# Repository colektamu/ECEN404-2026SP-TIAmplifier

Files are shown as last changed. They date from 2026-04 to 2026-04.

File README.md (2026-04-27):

The 2025-2026 TI Amplifier Capstone Project was a senior year capstone project under Texas A&M University and sponsored by Texas Instruments. The project was completed by Haotian Guan, Cole Keating, Braeden Murdock, and Jonathan Roman under the mentorship and supervision of Alex Anderson as a contact with Texas Instruments. The files included in this GitHub repository reflect the progress updates and final version of the project.

Each folder within the repository reflects a single subsystem that contributed to the final project. 
Braeden Murdock integrated pcb power subsystem contains files relevant to the power subsystem that powered the device. 
Cole - Pre and power amp contains the files relevant to the analog subsystem, both the preamp that modulated the signal and the power amp that amplified it into the speaker output. 
Microcontroller - Jonathan Roman contains the pcb and code files for the microcontroller subsystem, used to translate mobile app inputs into potentiometer states on the audio circuits.

All other files found in the repository without a set folder are related documentation such as the Functional System Requirements and Validation Plan.

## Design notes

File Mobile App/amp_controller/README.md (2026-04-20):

# amp_controller

A new Flutter project.

## Getting Started

This project is a starting point for a Flutter application.

A few resources to get you started if this is your first Flutter project:

- [Lab: Write your first Flutter app](https://docs.flutter.dev/get-started/codelab)
- [Cookbook: Useful Flutter samples](https://docs.flutter.dev/cookbook)

For help getting started with Flutter development, view the
[online documentation](https://docs.flutter.dev/), which offers tutorials,
samples, guidance on mobile development, and a full API reference.

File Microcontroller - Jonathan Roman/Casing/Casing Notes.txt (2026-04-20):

Included in the folder is just the STL output files produced. For the actual design process, the software used was Fusion under a student license, with the repository itself available through the following link:
https://a360.co/4tlYHgb

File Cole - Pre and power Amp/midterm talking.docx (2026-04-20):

- Discuss block diagram
  - State how input signal is about 1.4V amplitude
  - Produced from 3.5mm audio jack
- Preamp stage
  - Using Baxandall 3-band config
  - Will allow for attenuation of low, mid, high frequencies
  - Volume control
  - Gain of about 1
  - Using NE5532, industry standard audio dual op amp with low noise
  - Not rail to rail, but with 12V supply it will have enough headroom
  - Design will be refined through breadboard
  - Will eventually require bespoke pcb
- Amplifier Stage
  - Will use off the shelf amplifier chip
  - Will use powerful one and underdrive it for more headroom to reduce distortion
  - Class AB is a design using push/pull transistor config, commonly used for audio designs due to low distortion
  - Must have enough headroom in output to prevent THD of 10% at 5W
- Power constraints: Due to DC only design, we don’t have the ability to provide dual voltage rails.
  - With a 12V supply, will bias around 6V and use DC decoupling capacitors for output

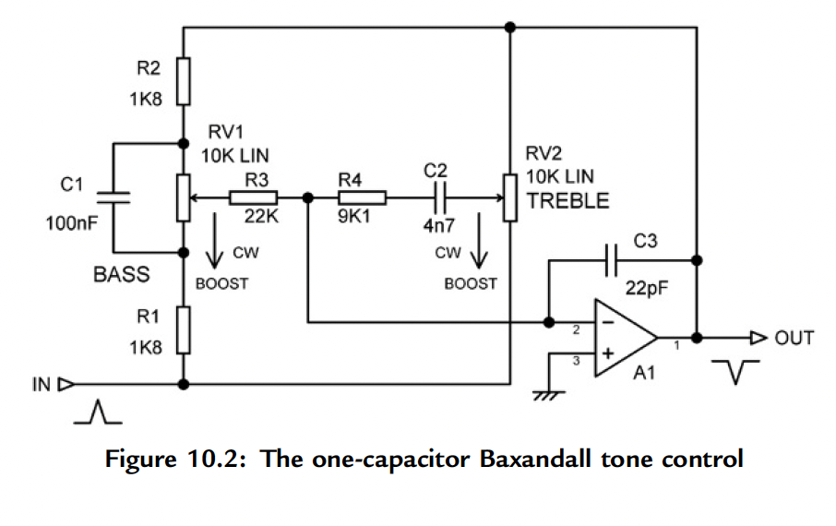
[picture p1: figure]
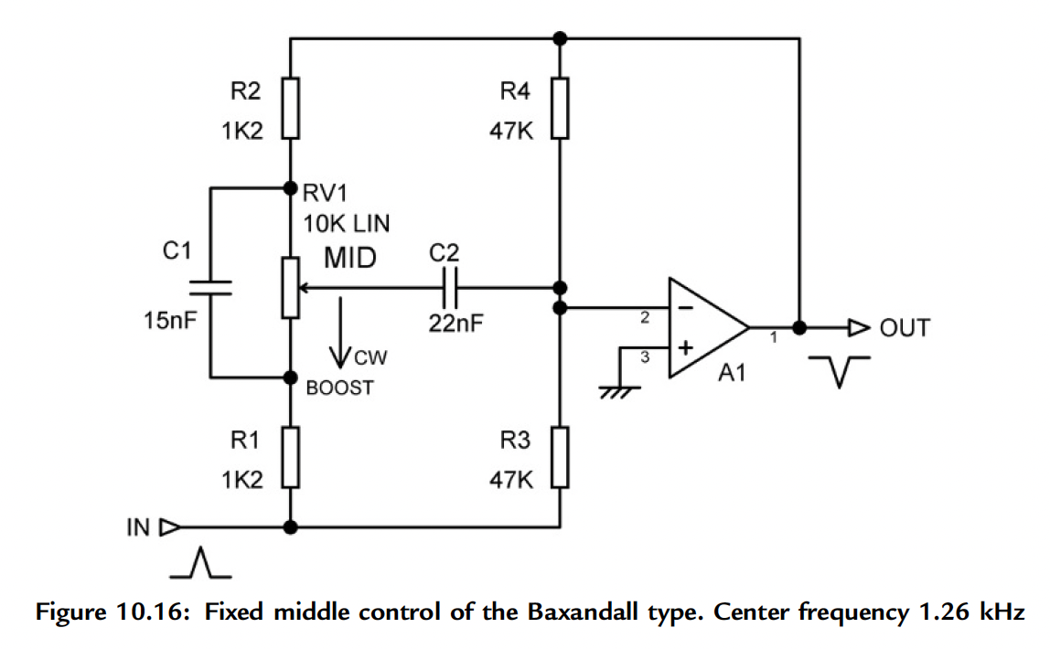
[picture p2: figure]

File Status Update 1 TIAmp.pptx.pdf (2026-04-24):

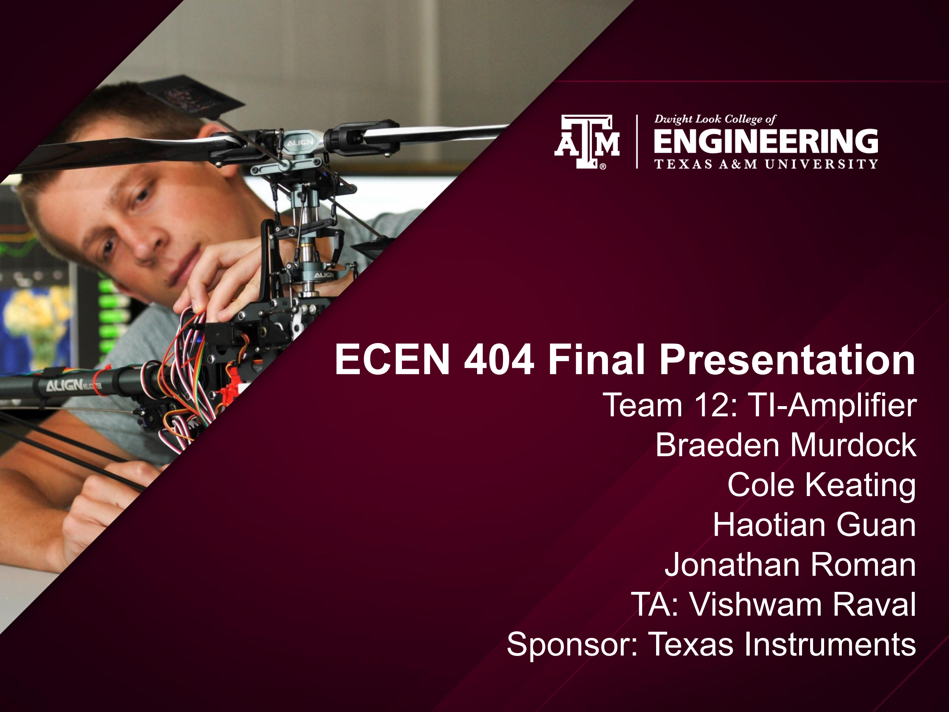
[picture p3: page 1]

# ECEN 404 Final Presentation

## Team 12: TI-Amplifier Braeden Murdock Cole Keating Haotian Guan Jonathan Roman TA: Vishwam Raval Sponsor: Texas Instruments

## Project Summary

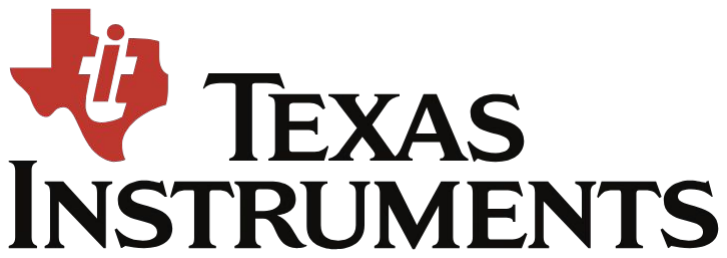
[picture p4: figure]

## Problem statement:

•Needs a system that can wirelessly amplify the sound of a 8Ω speaker from a mobile app.

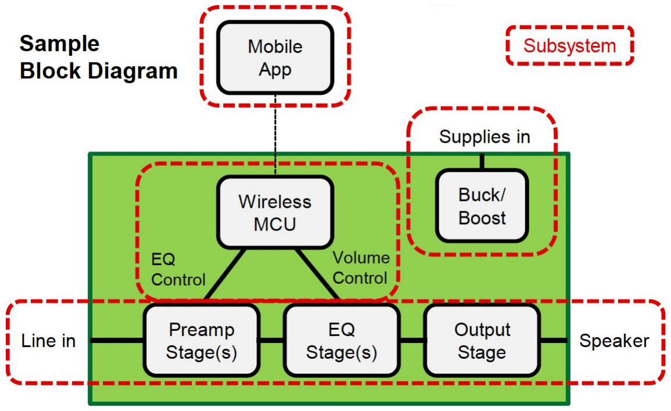
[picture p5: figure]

## Our Solution:

•The system being developed will use a MCU to communicate with a mobile app in order to control a system of amplifiers to adjust volume and EQ of the speaker using a aux input.

2

# System Overview

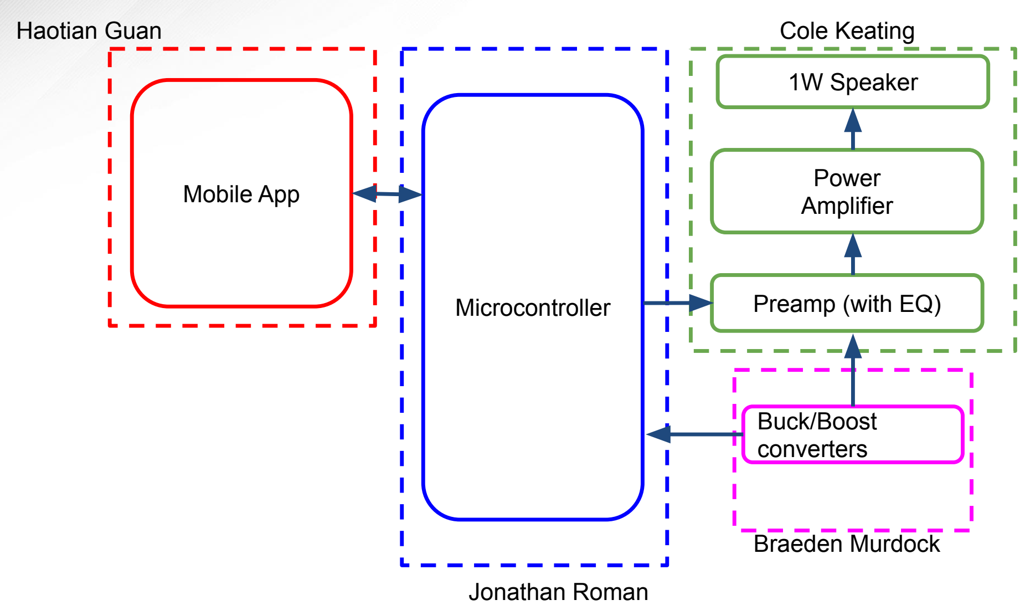
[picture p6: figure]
Haotian Guan; Jonathan Roman; Cole Keating; Braeden Murdock; Preamp (with EQ); Power Amplifier; Buck/Boost converters; 1W Speaker; Mobile App; Microcontroller

# Major Project Changes for 404 (45 sec)

Additional Tasks Taken on my Group Members:
Braedon Murdock:
- Integrated PCB Design

Cole Keating:
- Custom Power Amp Design

Isaac Roman:
- Final Integration Casing Design
- Integrated PCB Design (assistance)

No Major Project Changes at this time

# Project Timeline

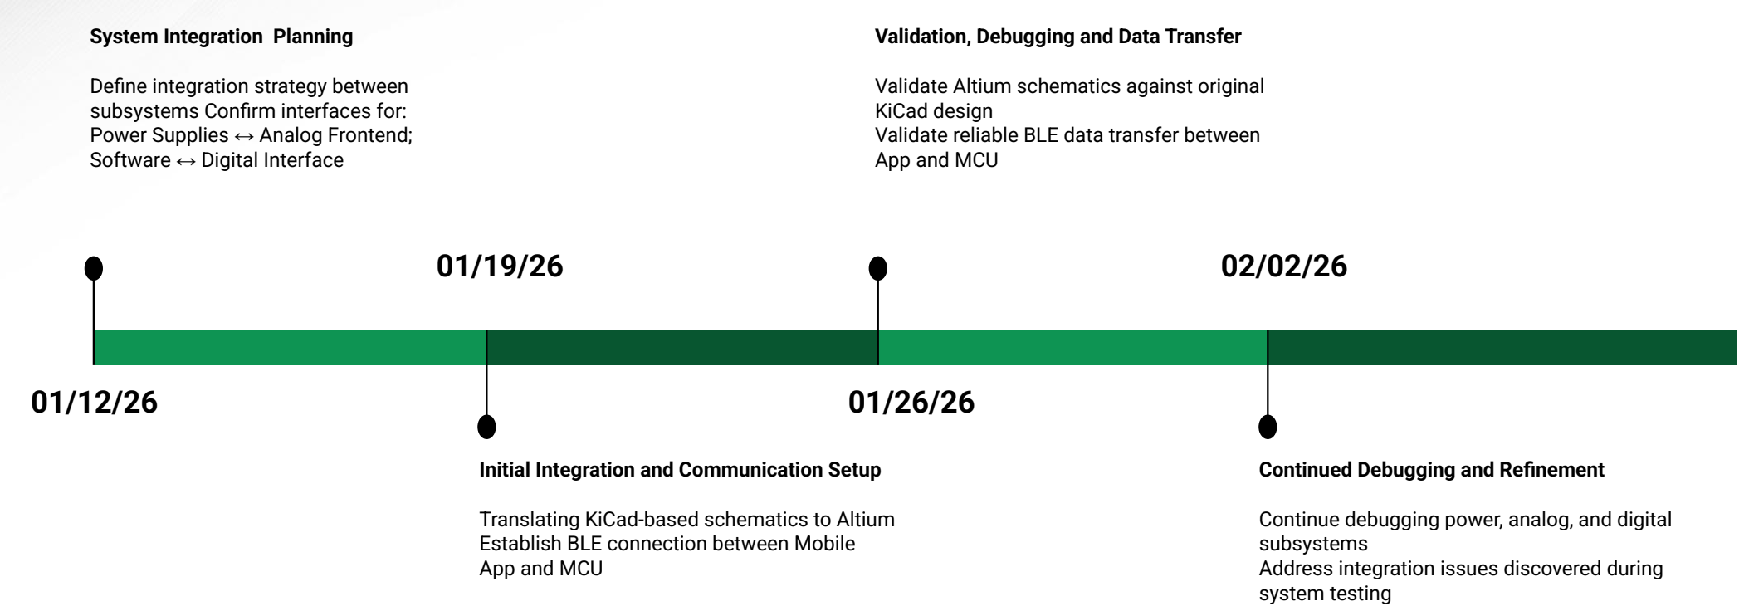
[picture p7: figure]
Validation, Debugging and Data Transfer; Validate Altium schematics against original KiCad design; App and MCU; Continued Debugging and Refinement; subsystems Address integration issues discovered during system testing; System Integration Planning; Define integration strategy between subsystems Confirm interfaces for: Power Supplies ↔ Analog Frontend; Software ↔ Digital Interface; Initial Integration and Communication Setup; Translating KiCad-based schematics to Altium Establish BLE connection between Mobile App and MCU

Validate reliable BLE data transfer between

Continue debugging power, analog, and digital

## Subsystem 1 - Mobile App

Haotian Guan

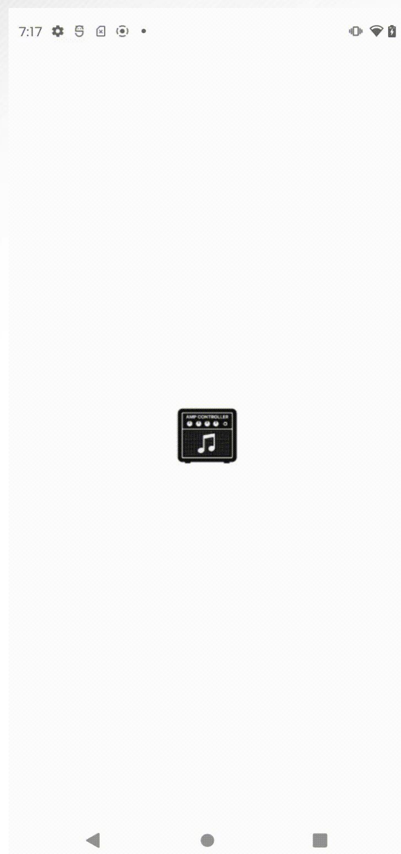
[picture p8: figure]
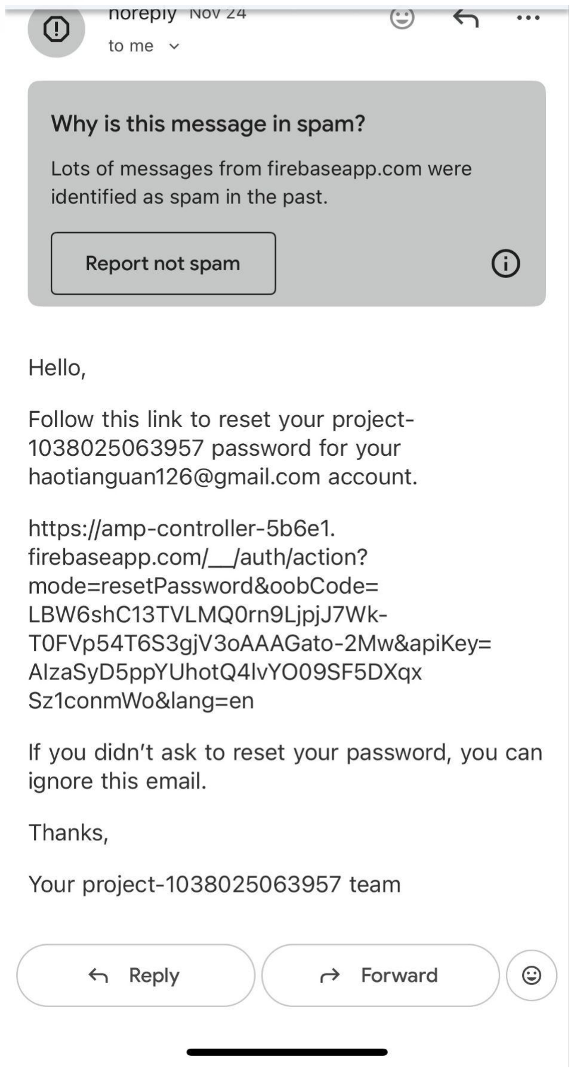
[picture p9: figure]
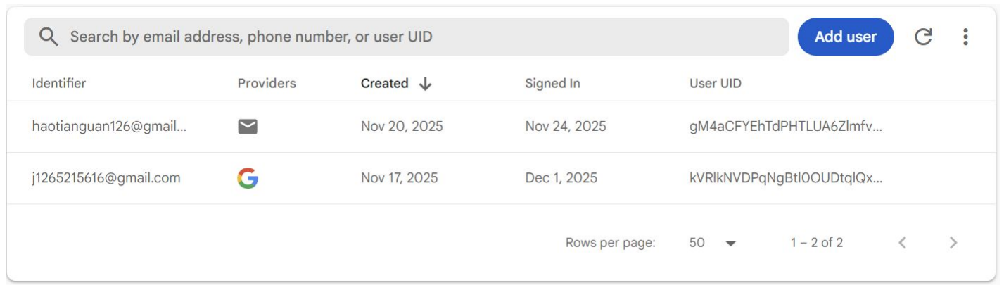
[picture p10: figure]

## Subsystem 1 - Mobile App

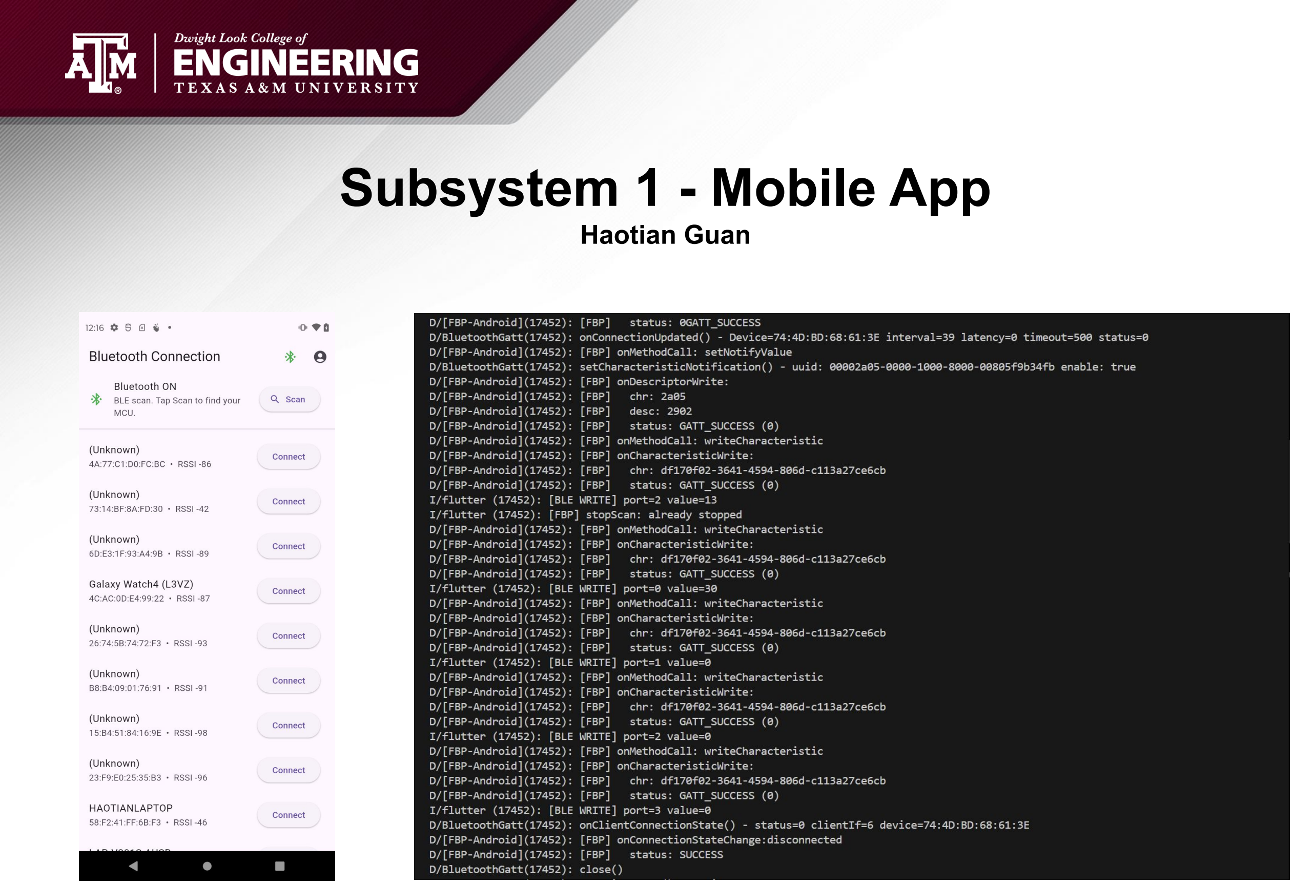
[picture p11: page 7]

Haotian Guan

## Subsystem 1 - Mobile App

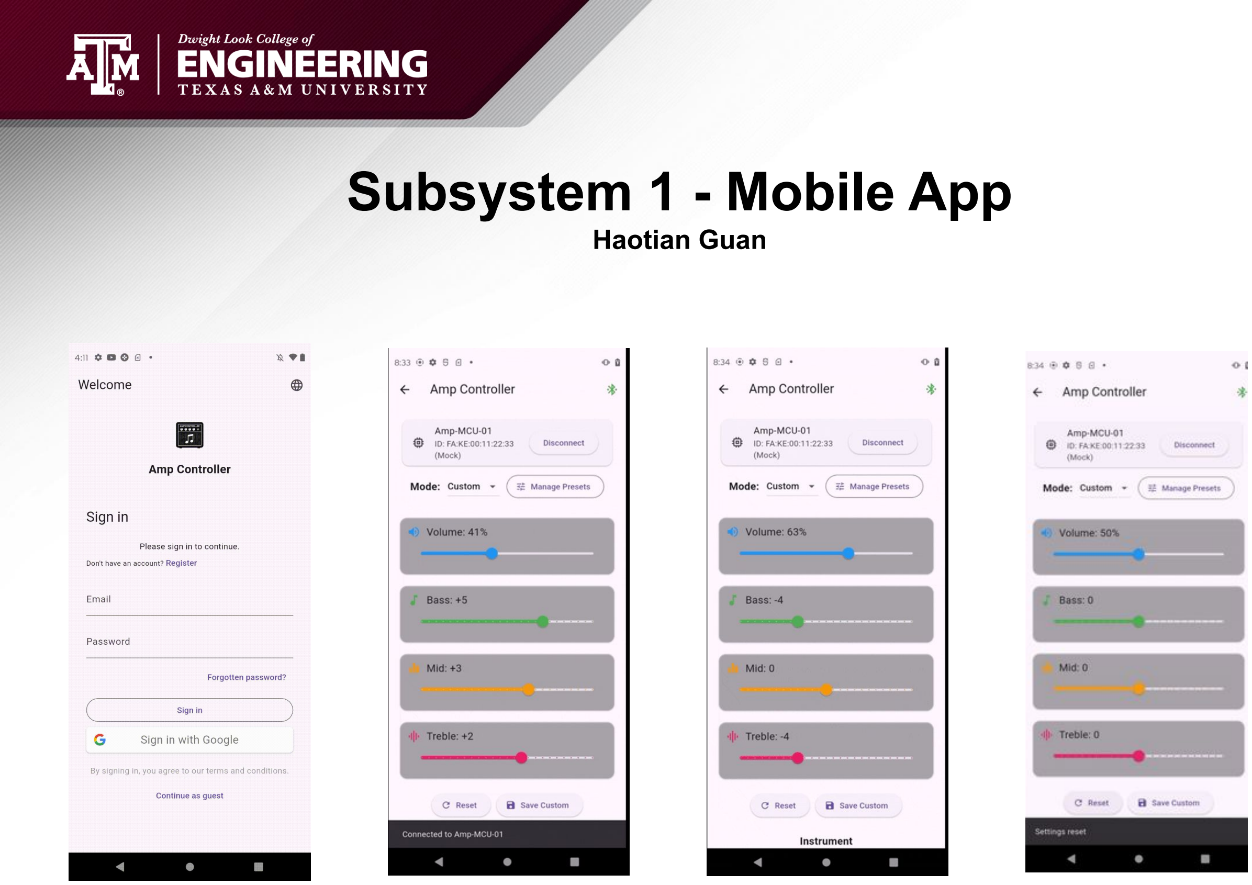
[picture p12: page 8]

Haotian Guan

# Subsystem 1 - Mobile App

Haotian Guan

Accomplishments since ECEN 403 25 hrs of effort

Ongoing progress/problems and plans until the next presentation

- Build the overall application architecture using Flutter
- Implement Firebase login and user verification
- Complete the BLE scanning and connection
- Design and implement the volume and EQ control interface
- Resolve issues such as connection stability and UI overflow.
- Implement localization
- Complete localization for the Firebase login page
- Complete cloud data management
- Continue testing with Jonathan that connection and data transmission from mobile app to MCU

## Subsystem 2 - Microcontroller

Jonathan Roman

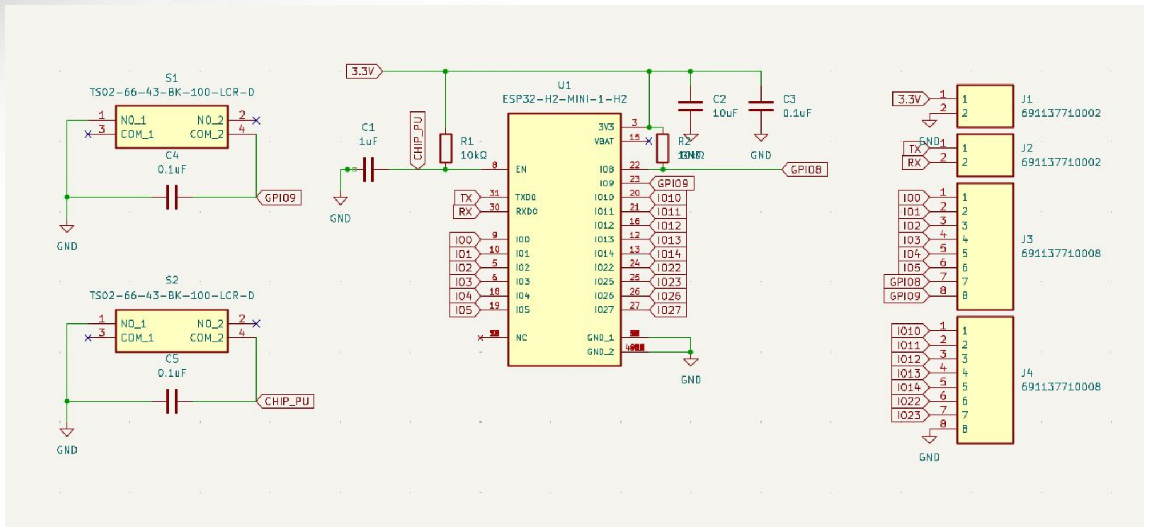
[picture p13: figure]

## Subsystem 2 - Microcontroller

Jonathan Roman

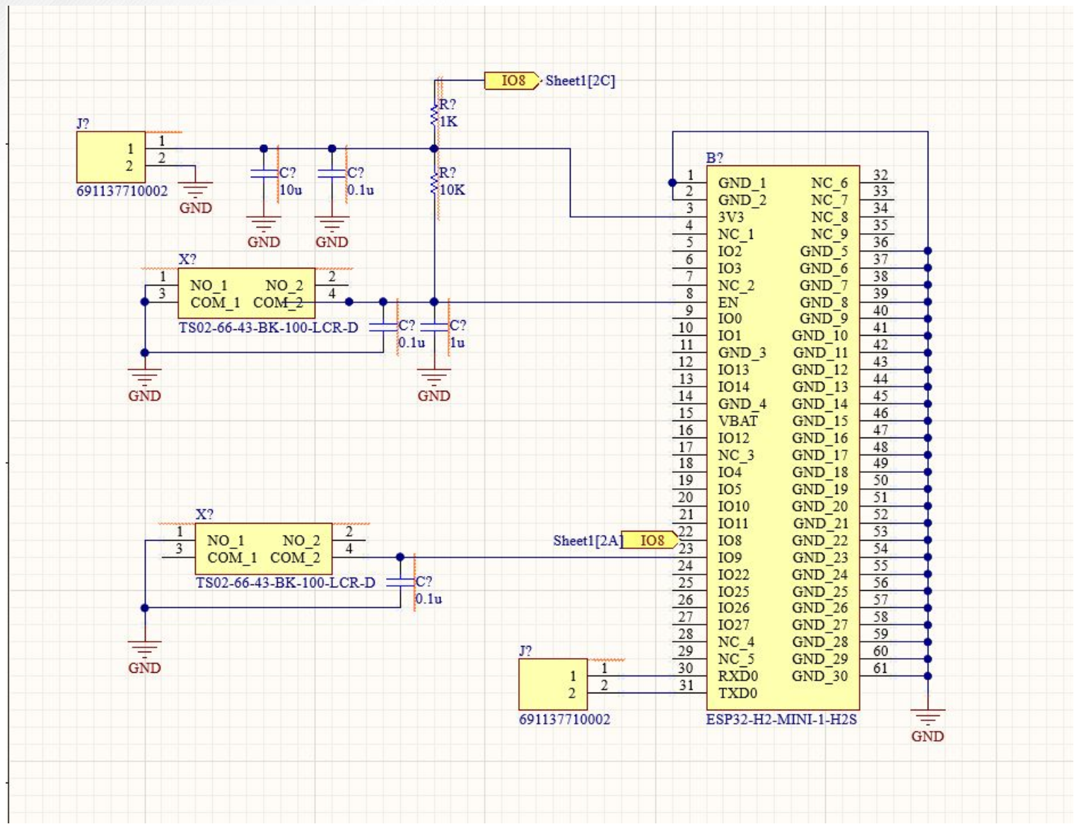
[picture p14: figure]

# Subsystem 2 - Microcontroller

Jonathan Roman

Accomplishments since ECEN 403 22 hrs of effort

Ongoing progress/problems and plans until the next presentation

- Redesigned and reordered MCU pcb in Kicad
- Recreated updated design in Altium for group integration
- Assisted with BLE connection with Mobile App
- Polish Altium design for smoother integration
- Acquire parts and begin soldering updated board for verification

## Subsystem 3 - Amplifier

Cole Keating

13

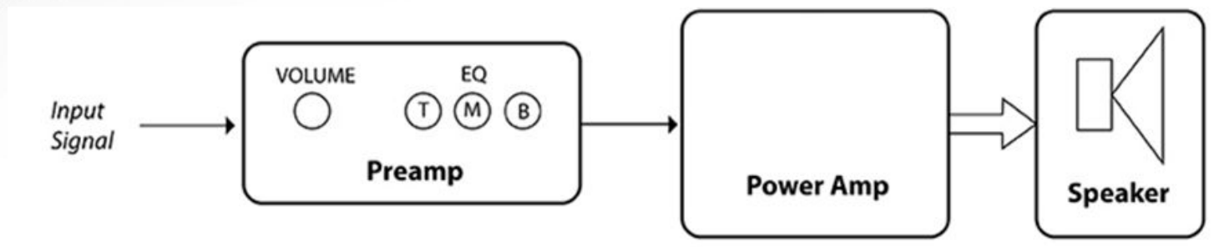
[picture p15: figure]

## Preamp

- 3 Band EQ: can boost/attenuate low, mid, high frequencies.
- Digital potentiometers from MCU will control low/mid/high
frequency gain, as well as volume control
- OPA1656 dual op amp selected -new, low noise design

## Power Amp

- Must provide 1W of power to an 8Ω speaker
- THD requirements:
<1% at 5W RMS,
<0.1% at 1W RMS
- Can use OTS (off-the-shelf) amplifier

# Design and Requirements:

## Subsystem 3 - Preamplifier

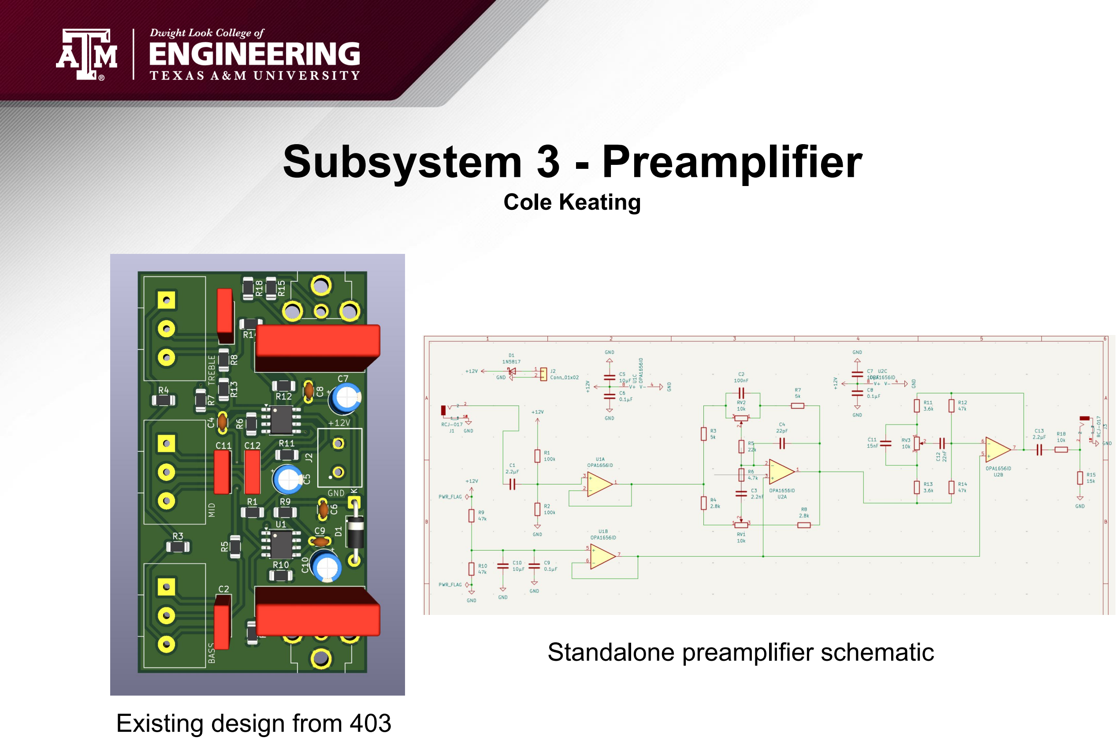
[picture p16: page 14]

Cole Keating

Existing design from 403

Standalone preamplifier schematic

## Subsystem 3 - Power Amplifier

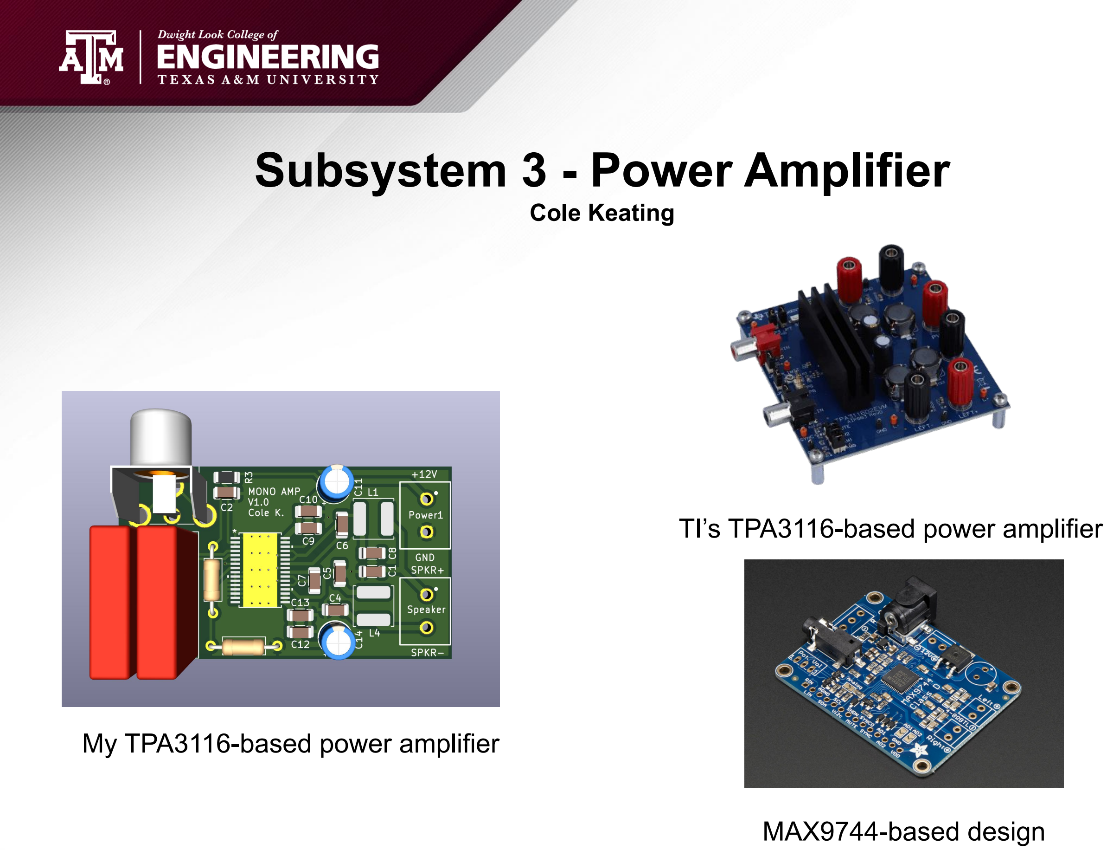
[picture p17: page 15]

Cole Keating

My TPA3116-based power amplifier

TI’s TPA3116-based power amplifier

MAX9744-based design

## Subsystem 3 - Preamplifier Integration

Cole Keating

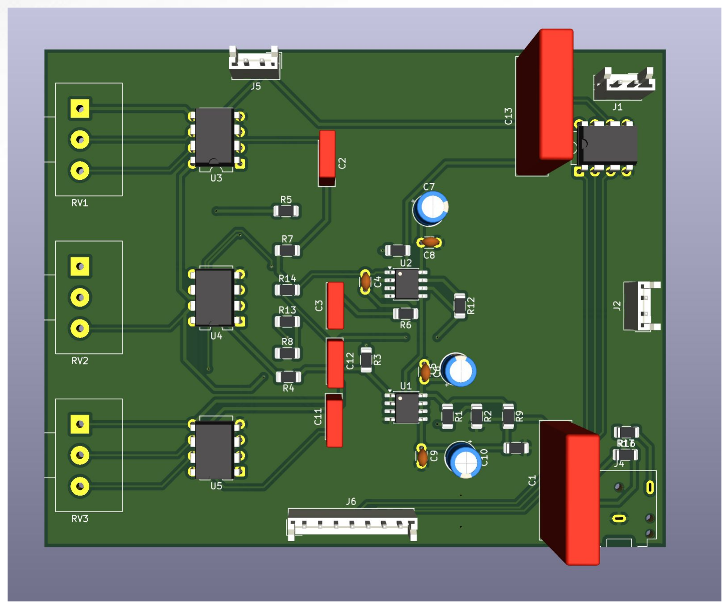
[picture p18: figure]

- New schematic was made replacing physical pots with digital pots to begin process of integrating MCU control
- This was done in KiCad, but we’ve agreed to use Altium for all designs moving forward
- Power amplifier will stay on separate PCB, but all low power subsystems will be on same board (Power, MCU, Preamp).

# Subsystem 3 - Amplifier

Cole Keating

Accomplishments since ECEN 403 20 hrs of effort

Ongoing progress/problems and plans until the next presentation

- Redesigned preamplifier to incorporate digital potentiometers
- Researched SPI vs I2C control, confirmed protocol for MCU integration
- Selected digital potentiometer that met design requirements (MCP4151)
- Updated existing preamplifier design to incorporate digital potentiometers to aid in integration
- Ordered and began examining TPA3116 power amplifier eval. board
- Finish debugging my
TPA3116-based design with the help of the EVM
- Test selected digital potentiometers before committing them to the PCB
- Ensure no errors when translating KiCad based schematics to Altium
- Work with Braeden to integrate our designs
- Get PCBs ordered early

## Power System

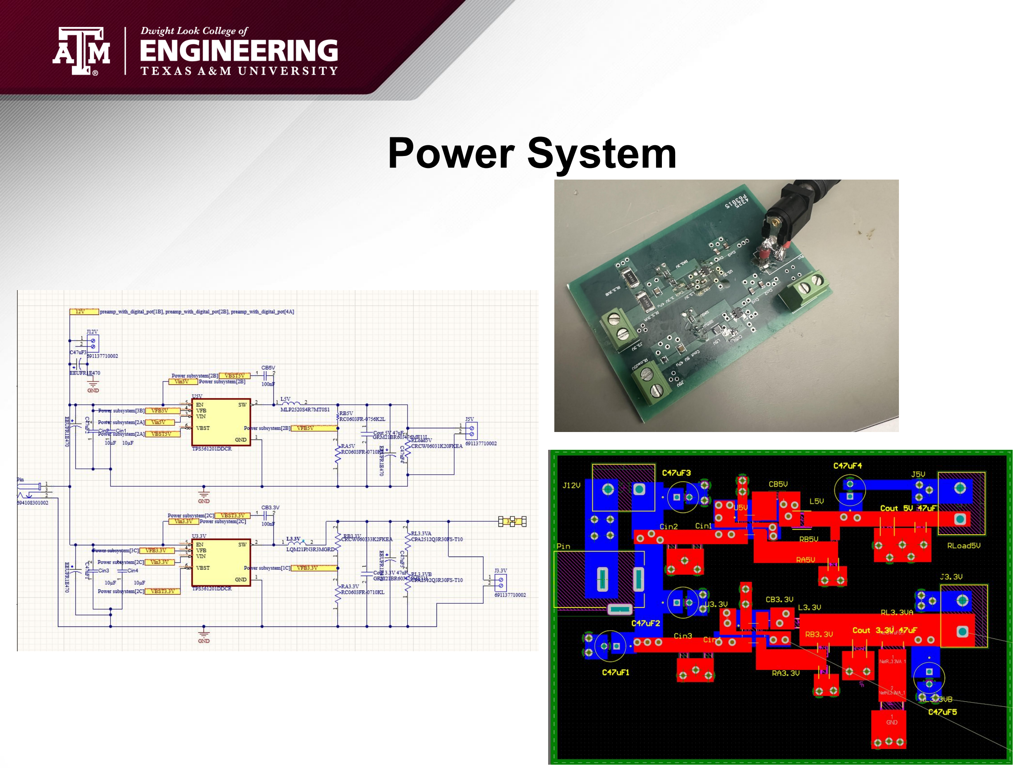
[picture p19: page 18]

# Preamplifier

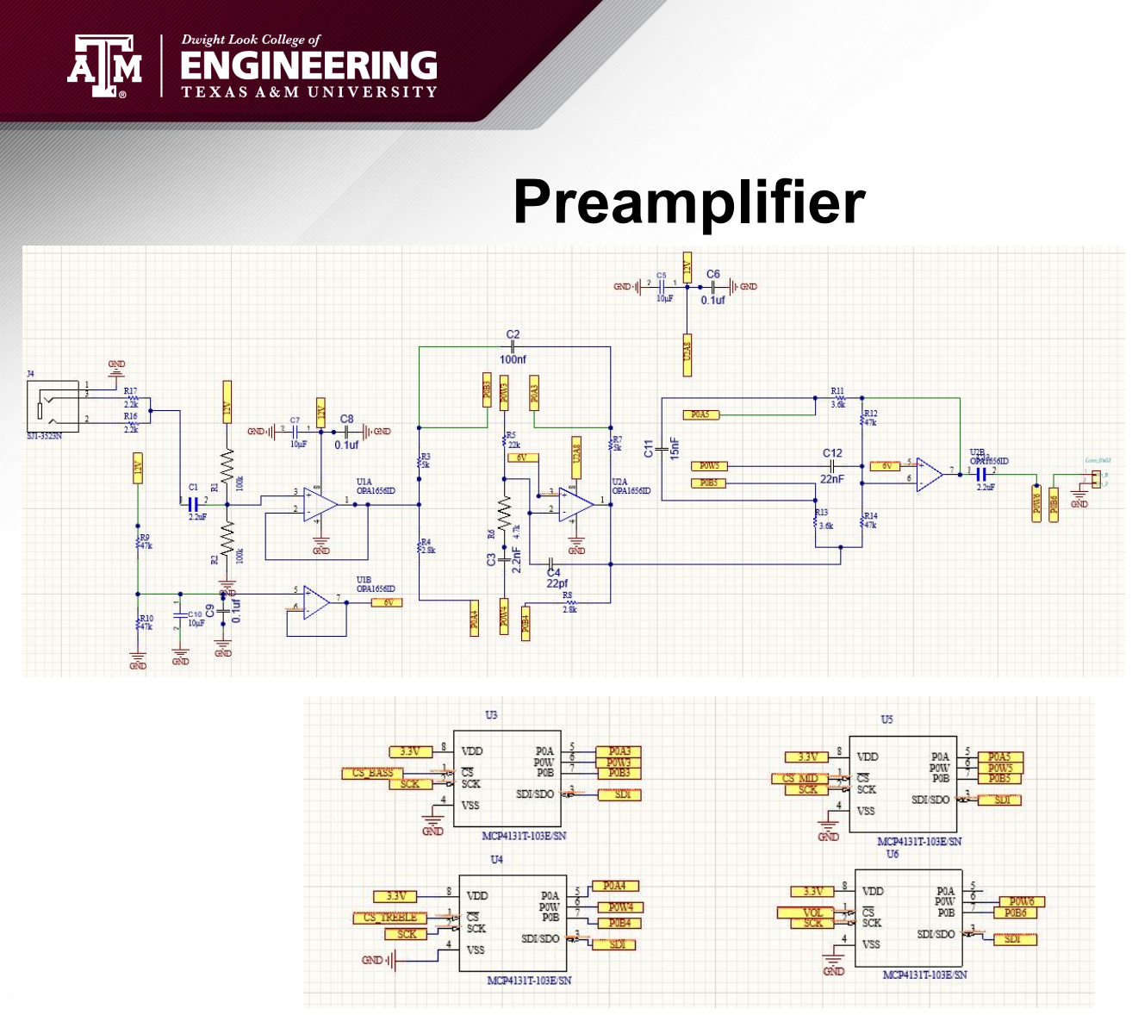
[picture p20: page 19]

# Subsystem 4 - Power System

Braeden Murdock
Accomplishments since 403
23 hrs of effort

Ongoing progress/problems and plans until the next presentation
- Rebuilt some of the Buck/boost subsystem for integration
- Remade the preamplifier
subsystem in altium
- Tested and added more
capacitors to help with voltage peak to peak on Power
subsystem
- Integrate MCU onto Final board
- Integrate preamplifier onto Final board
- Test with both Cole and
Jonathan that all the
subsystems work together

# Parts Ordering Status

To Be Ordered:
- Integrated PCB
- Finalized Component List
- Finalized Power Amp PCB

Ordered (Not Received):
- Updated MCU PCB & Additional Components (expected by this weekend)

# Validation Plan

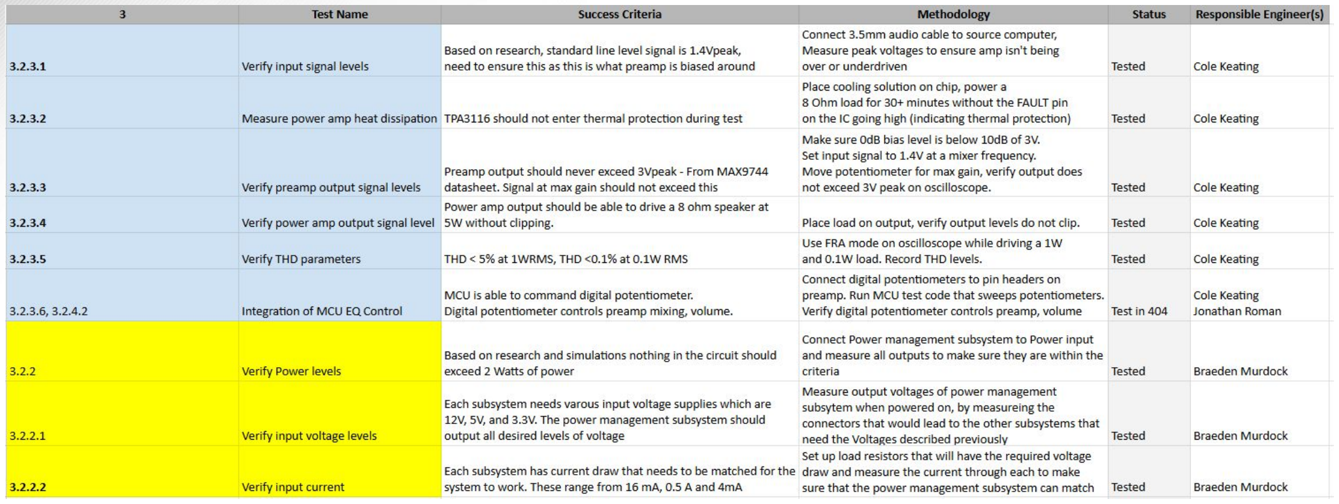
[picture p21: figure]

# Validation Plan Continued

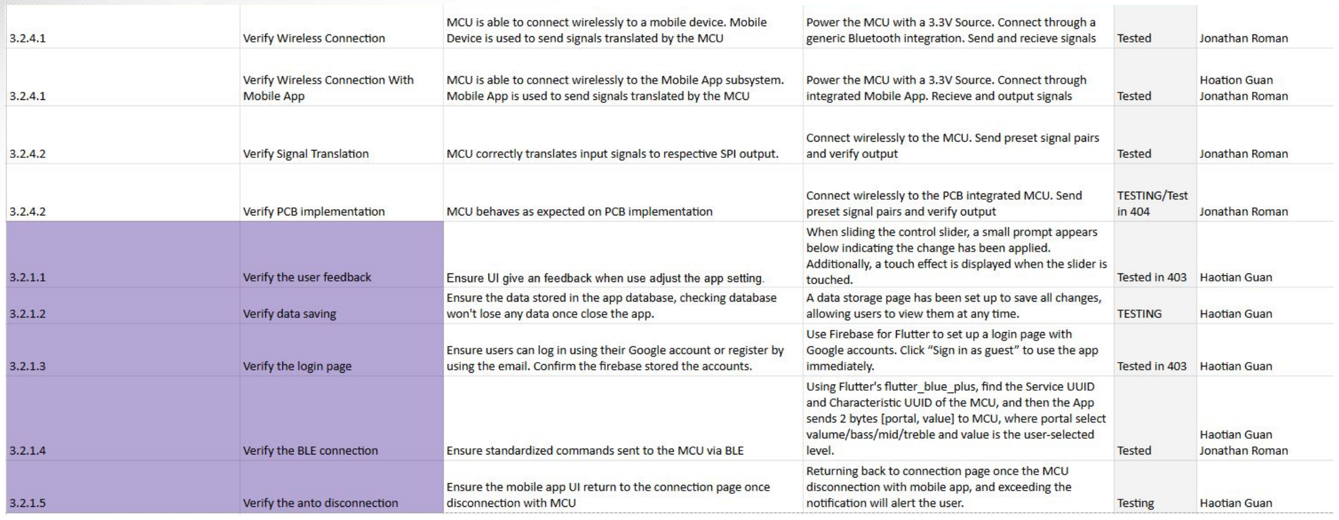
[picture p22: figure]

# Execution Plan

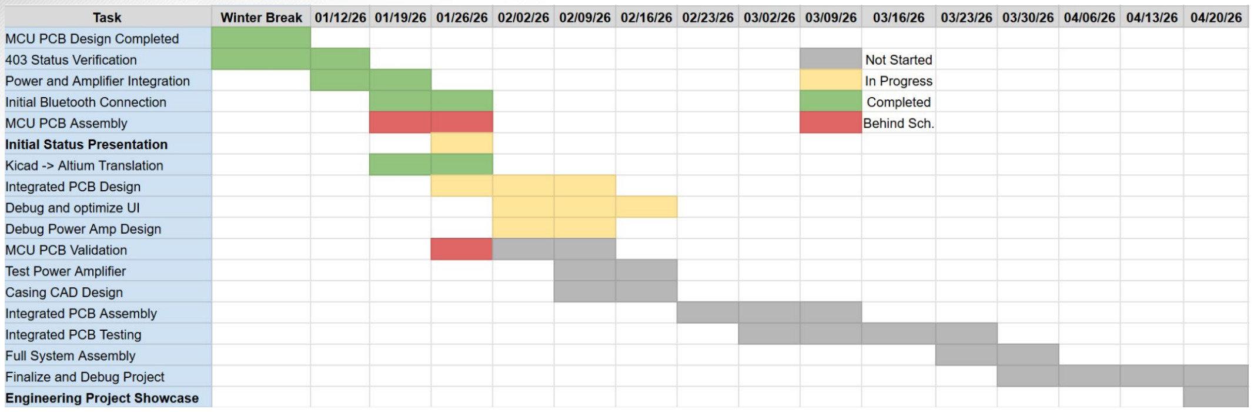
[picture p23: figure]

## Team 12 – TI-Amplifier Braeden Murdock Cole Keating Haotian Guan Jonathan Roman

## Thank you for your attention!

We appreciate your time and interest in our project. We’re happy to take any questions.

25

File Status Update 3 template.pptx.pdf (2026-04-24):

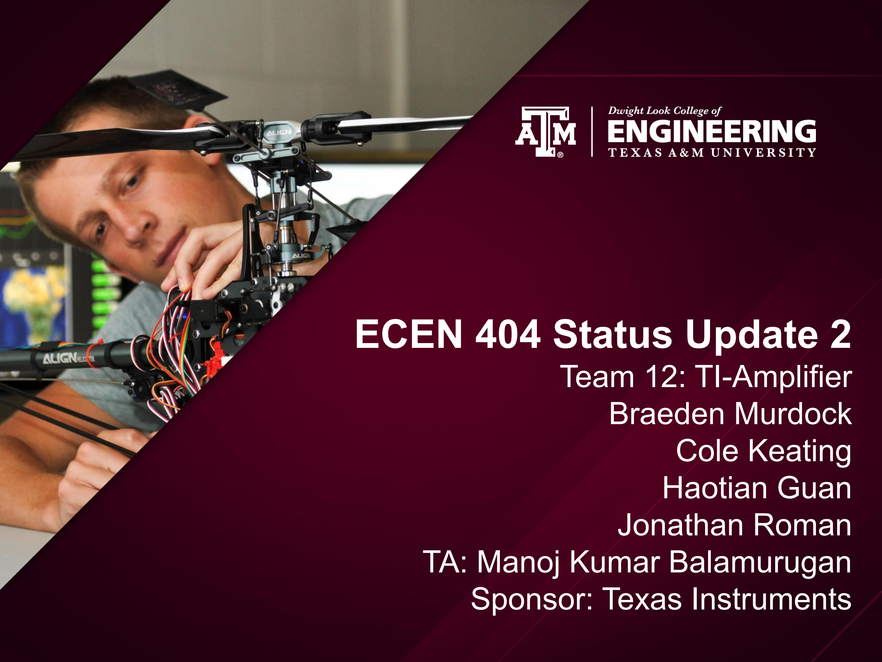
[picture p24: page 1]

# ECEN 404 Status Update 2

## Team 12: TI-Amplifier Braeden Murdock Cole Keating Haotian Guan Jonathan Roman TA: Manoj Kumar Balamurugan Sponsor: Texas Instruments

# Project Timeline

integrated PCB; subsystems Address integration issues discovered during system testing; Receive updated PCB and continue; Continue debugging UI; board; Continue Integration; combined board; Solder Integrated PCB; subsystems. Address any integration issues found.

Update and order the second iteration of the

Continue debugging power, analog, and digital

integration / continue to debug first iteration

Begin soldering the second iteration of the

Finish soldering and test functionality of

Solder the integrated PCB received with all

## Subsystem 1 - Mobile App

Haotian Guan


## Subsystem 1 - Mobile App


Haotian Guan

## Subsystem 1 - Mobile App


Haotian Guan

Localization | Volume and EQ Control | Preset Management | Electrical Piano

# Subsystem 1 - Mobile App

Haotian Guan

Accomplishments since last presentation 12 hrs of effort

Ongoing progress/problems and plans until the next presentation

- Implement connection detector | • Continue testing connection and data transmission from mobile app to MCU

## Subsystem 2 - Microcontroller

Jonathan Roman


## Subsystem 2 - Microcontroller


Jonathan Roman

## Subsystem 2 - Microcontroller


Jonathan Roman

# Subsystem 2 - Microcontroller

Jonathan Roman

Accomplishments since last presentation 30 hrs of effort

Ongoing progress/problems and plans until the next presentation

- Tested and Refined individual Subsystem Board
- Assisted in assembly of integrated board
- Debugged and tested the MCU on the integrated board
- Assisted in designing a base framework for an updated integrated board
- Continue testing on the integrated board
- Refine and order an updated integrated board

# Integrated Board


# Integrated Board Subsystem tests


# Subsystem 3 - Power System

Braeden Murdock
Accomplishments last presentation 30 hrs of effort | Ongoing progress/problems and plans until the next presentation
- Got the integrated PCB ● Got parts for the Power and preamplifier subsystems ● Tested the power subsystem | ● Do more tests on the current integrated PCB with Cole and Jonathan

## Subsystem 4 - Next Iteration of Integrated PCB

Cole Keating


## Subsystem 4 - Next Iteration of Integrated PCB

Cole Keating

## Changes made so far:

### - Switched ESP32 module to same model, but with a

hand-solderable footprint.

- Identified issue with digital potentiometer. voltage levels, upgraded to high voltage model of same chip.

### - Added debugging header for ESP32 module, more

silkscreen labelling for the many connectors on board.

### - Board is now two layers for quicker turnaround on PCB

manufacturing.

# Subsystem 4

Cole Keating

Accomplishments since last presentation 32 hrs of effort

Ongoing progress/problems and plans until the next presentation

- Designed next iteration of integrated PCB with Jonathan - will order after testing current one
- Helped assemble integrated board, participated in Blitz
- Recognized issue with digital potentiometers, integrated fix into new design
- Found temporary solution for current board
- Need lots of testing and verification on current integrated PCB before ordering next version
- Power Amp board needs to be assembled - this week

# Validation Plan


# Validation Plan Continued


# Execution Plan


## Team 12 – TI-Amplifier Braeden Murdock Cole Keating Haotian Guan Jonathan Roman

## Thank you for your attention!

We appreciate your time and interest in our project. We’re happy to take any questions.

20

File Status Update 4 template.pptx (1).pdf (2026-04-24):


# ECEN 404 Status Update 4

## Team 12: TI-Amplifier Braeden Murdock Cole Keating Haotian Guan Jonathan Roman TA: Manoj Kumar Balamurugan Sponsor: Texas Instruments

# Project Timeline

integrated PCB; subsystems Address integration issues discovered during system testing; Receive updated PCB and continue; Continue debugging UI; board; Continue Integration; combined board; PCB.

Update and order the second iteration of the

Continue debugging power, analog, and digital

integration / continue to debug first iteration

Begin soldering the second iteration of the

Finish soldering and test functionality of

Completed the integration of app and MCU

Keep testing the functionality of the combined

## Subsystem 1 - Mobile App

Haotian Guan


## Subsystem 1 - Mobile App


Haotian Guan

## Subsystem 1 - Mobile App


Haotian Guan

Localization | Volume and EQ Control | Preset Management | Electrical Piano

# Subsystem 1 - Mobile App

Haotian Guan

Accomplishments since last presentation 14 hrs of effort

Ongoing progress/problems and plans until the next presentation

- Completed the integration between app and MCU
- Fixed the issue where returning to the connection page after every time modifying parameters was caused by BLE connection detector
- Continue testing and debugging

## Subsystem 2 - Microcontroller


Jonathan Roman

## Subsystem 2 - Microcontroller

Jonathan Roman


# Subsystem 2 - Microcontroller

Jonathan Roman

Accomplishments since last presentation 18 hrs of effort

Ongoing progress/problems and plans until the next presentation

- Tested and Refined individual Subsystem Board against Dev Board
- Debugged and Reworked code to fix SPI send
- Continue testing on the integrated board
- Assemble and Debug Integrated board

# Integrated Board


# Integrated Board Subsystem tests


# Subsystem 3 - Power System

Braeden Murdock
Accomplishments last presentation 22 hrs of effort | Ongoing progress/problems and plans until the next presentation
- Assisted in finding bug in code that was revealed to be source of failure for MCU sending data to pots ● Found reason MCU pin burned out | ● Build and get newly acquired pcb working using the knowledge gained from testing current integrated boad

## Subsystem 4 - Next Iteration of Integrated PCB

Cole Keating


## Subsystem 4 - Next Iteration of Integrated PCB

Cole Keating

### - Newest revision addressing issues found during testing of original integrated PCB

### - New footprint for hand-solderable ESP32, added missing pullup resistors that had to be bodged on original design

- Addresses issues regarding voltage levels for digital pots,

### board redesigned for higher voltage model of potentiometer

### - Added final op amp buffer to address signal degradation issues observed during testing

## Subsystem 4 - Assembled Power Amp

Cole Keating


# Subsystem 4

Cole Keating

Accomplishments since last presentation 32 hrs of effort

Ongoing progress/problems and plans until the next presentation

- Tested initial integrated design, verified functionality of digital pot control
- Designed new integrated PCB with several fixes for issues that arose during testing
- Assembled and tested Power Amp, verified output levels and thermal performance
- Current revision of integrated PCB ordered before spring break, should arrive early this week
- Power Amp board needs to be assembled - this week

# Validation Plan


# Validation Plan Continued


# Execution Plan


## Team 12 – TI-Amplifier Braeden Murdock Cole Keating Haotian Guan Jonathan Roman

## Thank you for your attention!

We appreciate your time and interest in our project. We’re happy to take any questions.

20

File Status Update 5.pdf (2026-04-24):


# ECEN 404 Status Update 5

## Team 12: TI-Amplifier Braeden Murdock Cole Keating Haotian Guan Jonathan Roman TA: Manoj Kumar Balamurugan Sponsor: Texas Instruments

# Project Summary


# Problem statement:

## •Needs a system that can wirelessly amplify the sound of a 8Ω speaker

from a mobile app.


# Our Solution:

## •The system being developed will use a MCU to communicate with a mobile app in order to control a system of amplifiers to adjust volume and EQ of the speaker

using a aux input.

# Integrated System Diagram


# Project Timeline

Subsystem
Designs and
Testing
(completed 1/26)

Integration of
Mobile App and
MCU
(completed 2/2)

Complete first
revision of
integrated PCB
(completed 2/16)

System Test
(completed 3/2)

Completion of Final
Integrated PCB
(completed 3/16)

Validation
(to complete by
4/6)

Demo and
Report
(to complete by
4/13)

# Subsystem 1 - Mobile App

Haotian Guan

Accomplishments since last presentation 17 hrs of effort

Ongoing progress/problems and plans until the next presentation

- Completed an background theme selection UI
- Fixed the issue where control page keep returning back to connection page in skip connection mode.
- Builded an apk.
- Continue testing and debugging

# Subsystem 1 - Mobile App


Haotian Guan

# Subsystem 1 - Mobile App


Haotian Guan

# Subsystem 1 - Mobile App


Haotian Guan

Localization | Volume and EQ Control | Preset and Mode | Theme and Piano

# Subsystem 2 - Microcontroller

Jonathan Roman

## Accomplishments last presentation 20 hrs of effort

## Ongoing progress/problems and plans until the next presentation

## - Validated MCU operations on integrated PCB - Assisted in testing for other integrated subsystems

## - Continue Assisting in Pre-amp validation - Refine and Debug code for new ESP model - Design housing for full system using CAD

# Subsystem 3 - Microcontroller

Jonathan Roman

Previous Iteration of PCB was used to find all bugs for New PCB the list of bugs found and solutions are as follow

Bug | Solution
Incompatible header files for current integration | Replaced relevant header files and updated code
Connection Errors leading to bad signals | Resolder key connections and verify functionality
BLE Connection Issues | Formatting differences overlooked in header transfer

# Subsystem 3 - Power System

Braeden Murdock

## Accomplishments last presentation 26 hrs of effort

## Ongoing progress/problems and plans until the next presentation

## - Validated Power System on new PCB to make sure it worked as expected - Helped in Debugging Current PCB noise Issue with Cole

## - Continue Assisting in Pre-amp validation - Help Jonathan in building the housing for entire system using CAD

# Subsystem 3 -Power System

Braeden Murdock

Previous Iteration of PCB was used to find all bugs for New PCB the list of bugs found and solutions are as follow

Expected Power on Rail | Actual Power on Rail
12V | 12.43V
3.3V | 3.371V
Bug | Solution
MCU failed to send signal to digital pots | Digital pots required 16 total bits sent across two 8 bit signals instead of the 1 8 bit we were sending before
Digital Pot held high at 5 V when should be at 3.3V | MCU pin was burned out due to prior testing and caused it to send a constant read command instead of write command

# Subsystem 4 - Analog Section


Cole Keating

Newest PCB revision
with HV pots

Flat response through pots -no passive degradation of
audio signal

Testing of increased gain
in bass, treble frequencies

# Subsystem 4 - Power Amp


Cole Keating

Finished Power Amp

# Subsystem 4 - Analog Section

Cole Keating

Accomplishments since last update 20 hrs of effort

Ongoing progress/problems and plans until the next presentation

- Corrected major issue with oscillation in mid stage
- Validated signal integrity through preamp section
- Validated efficacy of digital pots in audio role
- ONGOING - Validate increased gain using high voltage pots
- Validate all past tests on new iteration of PCB - minimal changes, don’t anticipate issues
- Need to order high wattage load resistor to validate maximum gain of power amp

# Execution Plan


# Validation Plan


# Validation Plan Continued


## Team 12 – TI-Amplifier Braeden Murdock Cole Keating Haotian Guan Jonathan Roman

## Thank you for your attention!

We appreciate your time and interest in our project. We’re happy to take any questions.

19

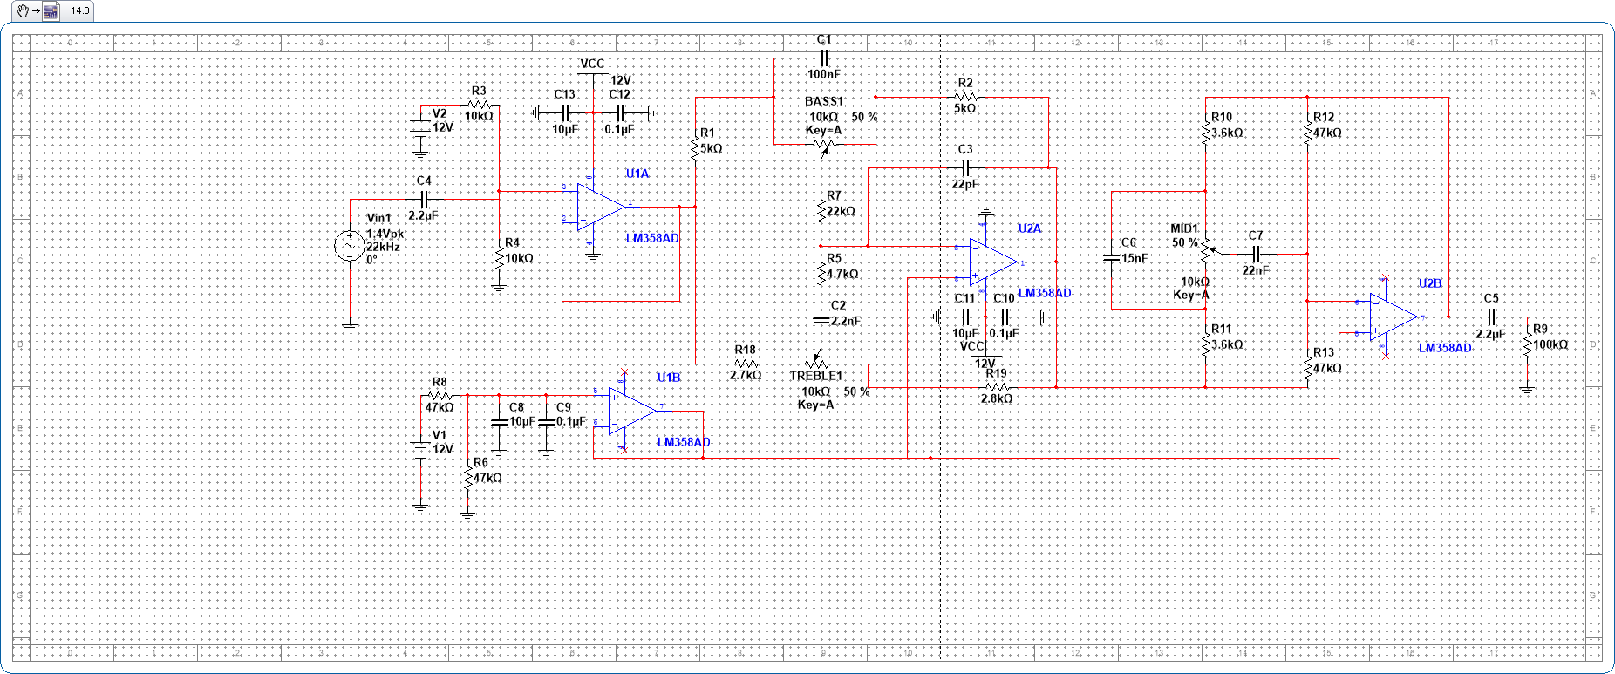
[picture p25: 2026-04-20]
Cole - Pre and power Amp/design.png

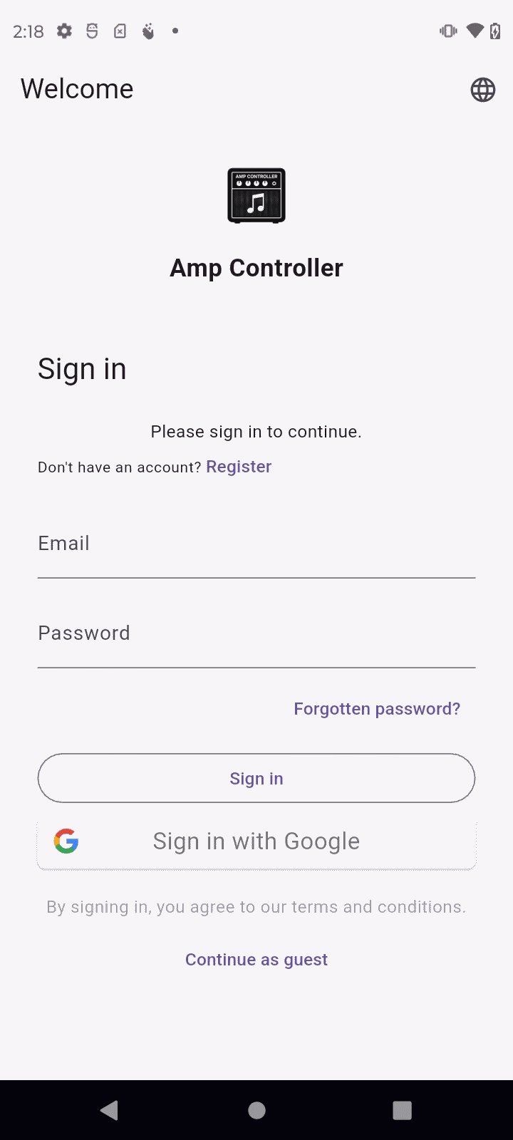
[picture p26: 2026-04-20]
Mobile App/localization.gif

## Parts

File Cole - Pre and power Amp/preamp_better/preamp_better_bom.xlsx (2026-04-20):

Reference | Qty | Value | LINK | Exclude from BOM | Exclude from Board | Footprint | Datasheet
C1,C13 | 2 | 2.2ŒºF |  |  |  | Capacitor_THT:C_Rect_L19.0mm_W5.0mm_P15.00mm_MKS4 | https://www.mouser.com/ProductDetail/871-B32522C225J
C2 | 1 | 100nF |  |  |  | Capacitor_THT:C_Rect_L7.2mm_W2.5mm_P5.00mm_FKS2_FKP2_MKS2_MKP2 | https://www.mouser.com/ProductDetail/Vishay-BC-Components/K104K10X7RF5UH5?qs=rLgk8CAOBHbAqIwDswVbzA%3D%3D
C3 | 1 | 2.2nF |  |  |  | Capacitor_THT:C_Rect_L7.2mm_W2.5mm_P5.00mm_FKS2_FKP2_MKS2_MKP2 | https://www.mouser.com/ProductDetail/Vishay-BC-Components/K222K10X7RF5UH5?qs=G7Q6MbuZsROajKg5%2F1buvg%3D%3D
C4 | 1 | 22pF |  |  |  | Capacitor_THT:C_Disc_D3.0mm_W1.6mm_P2.50mm | https://www.mouser.com/ProductDetail/594-K220J15C0GF5TL2
C5,C7,C10 | 3 | 10ŒºF |  |  |  | Capacitor_THT:CP_Radial_D5.0mm_P2.00mm | https://www.mouser.com/ProductDetail/232-50YXJ10M5X11
C6,C8,C9 | 3 | 0.1ŒºF |  |  |  | Capacitor_THT:C_Disc_D3.0mm_W1.6mm_P2.50mm | https://www.mouser.com/ProductDetail/594-K104K15X7RF5TL2
C11 | 1 | 15nF |  |  |  | Capacitor_THT:C_Rect_L7.2mm_W2.5mm_P5.00mm_FKS2_FKP2_MKS2_MKP2 | https://www.mouser.com/ProductDetail/594-K153K10X7RF5UH5
C12 | 1 | 22nF |  |  |  | Capacitor_THT:C_Rect_L7.2mm_W2.5mm_P5.00mm_FKS2_FKP2_MKS2_MKP2 | https://www.mouser.com/ProductDetail/Vishay-BC-Components/K223K10X7RF5UH5?qs=uwenMUmGrtfrOc4teMLlzQ%3D%3D
J1,J3 | 2 | AudioJack3_Ground |  |  |  | Connector_Audio:Jack_3.5mm_CUI_SJ1-3523N_Horizontal | https://www.mouser.com/ProductDetail/490-SJ1-3523N
J2 | 1 | Conn_01x02 |  |  |  | Connector_JST:JST_XH_B2B-XH-A_1x02_P2.50mm_Vertical | https://www.mouser.com/ProductDetail/JST-Commercial/B2B-XH-ALFSN?qs=cdbOS8ANM9DdcSn9qRmfCw%3D%3D
R1,R2 | 2 | 100k |  |  |  | Resistor_SMD:R_1206_3216Metric | https://www.mouser.com/ProductDetail/603-RC1206FR-07100KL
R3,R7 | 2 | 5k |  |  |  | Resistor_SMD:R_1206_3216Metric | https://www.mouser.com/ProductDetail/603-RC1206FR-074K99L
R4,R8 | 2 | 2.8k |  |  |  | Resistor_SMD:R_1206_3216Metric | https://www.mouser.com/ProductDetail/603-RC1206FR-072K8L
R5 | 1 | 22k |  |  |  | Resistor_SMD:R_1206_3216Metric | https://www.mouser.com/ProductDetail/603-RC1206FR-1022KL
R6 | 1 | 4.7k |  |  |  | Resistor_SMD:R_1206_3216Metric | https://www.mouser.com/ProductDetail/603-RC1206FR-074K7L
R9,R10,R12,R14 | 4 | 47k |  |  |  | Resistor_SMD:R_1206_3216Metric | https://www.mouser.com/ProductDetail/603-RC1206FR-0747KL
R11,R13 | 2 | 3.6k |  |  |  | Resistor_SMD:R_1206_3216Metric | https://www.mouser.com/ProductDetail/YAGEO/RC1206FR-073K6L?qs=bz%2FLPVPAsTKY3prSUkhPsQ%3D%3D
R15 | 1 | 15k |  |  |  | Resistor_SMD:R_1206_3216Metric | https://www.mouser.com/ProductDetail/YAGEO/RC1206FR-0715KL?qs=UiDTtNFP6s8%2FApGfkJFi6A%3D%3D
R16,R17,R18 | 3 | 10k |  |  |  | Resistor_SMD:R_1206_3216Metric | https://www.mouser.com/ProductDetail/YAGEO/RC1206FR-0710KL?qs=%252BhB4WxZmbVEJV82xdVgRUw%3D%3D
RV1,RV2,RV3 | 3 | 10k |  |  |  | Potentiometer_THT:Potentiometer_Alps_RK163_Single_Horizontal
U1,U2 | 2 | OPA1656ID |  |  |  | Package_SO:SOIC-8_3.9x4.9mm_P1.27mm | https://www.ti.com/lit/ds/symlink/opa1656.pdf

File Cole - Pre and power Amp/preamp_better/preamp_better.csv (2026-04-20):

Reference | Qty | Value | DNP | Exclude from BOM | Exclude from Board | Footprint | Datasheet
C1,C13 | 2 | 2.2μF |  |  |  | Capacitor_THT:C_Rect_L19.0mm_W5.0mm_P15.00mm_MKS4 | ~
C2 | 1 | 100nF |  |  |  | Capacitor_THT:C_Rect_L7.2mm_W2.5mm_P5.00mm_FKS2_FKP2_MKS2_MKP2 | ~
C3 | 1 | 2.2nF |  |  |  | Capacitor_THT:C_Rect_L7.2mm_W2.5mm_P5.00mm_FKS2_FKP2_MKS2_MKP2 | ~
C4 | 1 | 22pF |  |  |  | Capacitor_THT:C_Disc_D3.0mm_W1.6mm_P2.50mm | ~
C5,C7,C10 | 3 | 10μF |  |  |  | Capacitor_THT:CP_Radial_D5.0mm_P2.00mm | ~
C6,C8,C9 | 3 | 0.1μF |  |  |  | Capacitor_THT:C_Disc_D3.0mm_W1.6mm_P2.50mm | ~
C11 | 1 | 15nF |  |  |  | Capacitor_THT:C_Rect_L7.2mm_W2.5mm_P5.00mm_FKS2_FKP2_MKS2_MKP2 | ~
C12 | 1 | 22nF |  |  |  | Capacitor_THT:C_Rect_L7.2mm_W2.5mm_P5.00mm_FKS2_FKP2_MKS2_MKP2 | ~
J1,J3 | 2 | AudioJack3_Ground |  |  |  | Connector_Audio:Jack_3.5mm_CUI_SJ1-3523N_Horizontal | ~
J2 | 1 | Conn_01x02 |  |  |  | Connector_JST:JST_XH_B2B-XH-A_1x02_P2.50mm_Vertical | ~
R1,R2 | 2 | 100k |  |  |  | Resistor_SMD:R_1206_3216Metric | ~
R3,R7 | 2 | 5k |  |  |  | Resistor_SMD:R_1206_3216Metric | ~
R4,R8 | 2 | 2.8k |  |  |  | Resistor_SMD:R_1206_3216Metric | ~
R5 | 1 | 22k |  |  |  | Resistor_SMD:R_1206_3216Metric | ~
R6 | 1 | 4.7k |  |  |  | Resistor_SMD:R_1206_3216Metric | ~
R9,R10,R12,R14 | 4 | 47k |  |  |  | Resistor_SMD:R_1206_3216Metric | ~
R11,R13 | 2 | 3.6k |  |  |  | Resistor_SMD:R_1206_3216Metric | ~
R15 | 1 | 15k |  |  |  | Resistor_SMD:R_1206_3216Metric | ~
R16,R17,R18 | 3 | 10k |  |  |  | Resistor_SMD:R_1206_3216Metric | ~
RV1,RV2,RV3 | 3 | 10k |  |  |  | Potentiometer_THT:Potentiometer_Alps_RK163_Single_Horizontal | ~
U1,U2 | 2 | OPA1656ID |  |  |  | Package_SO:SOIC-8_3.9x4.9mm_P1.27mm | https://www.ti.com/lit/ds/symlink/opa1656.pdf

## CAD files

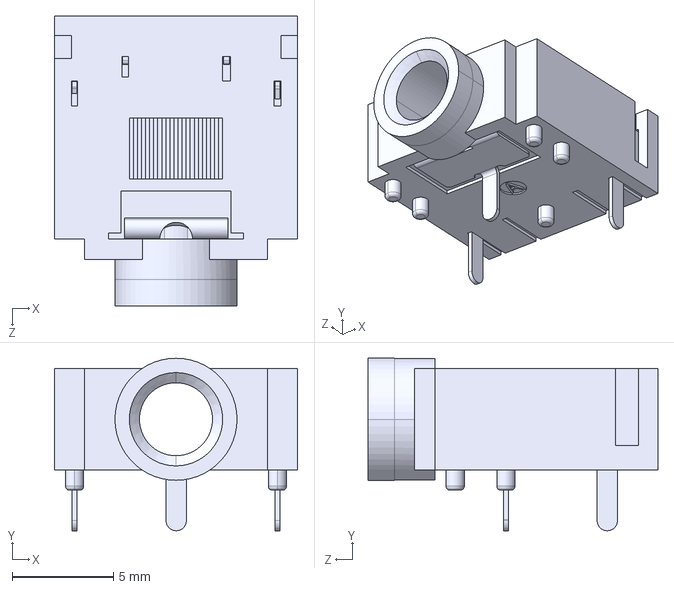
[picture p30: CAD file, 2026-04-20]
Cole - Pre and power Amp/aio_pcb/SJ1-3523N/SJ1-3523N.step
12.0 x 8.51 x 14.3 mm

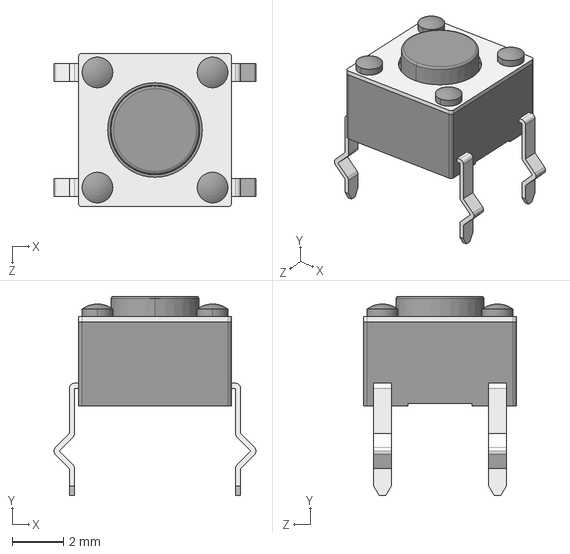
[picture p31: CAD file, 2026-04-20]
Cole - Pre and power Amp/aio_pcb/TS02_66_43_BK_100_LCR_D/TS02-66-43-BK-100-LCR-D.step
7.90 x 7.80 x 6.00 mm

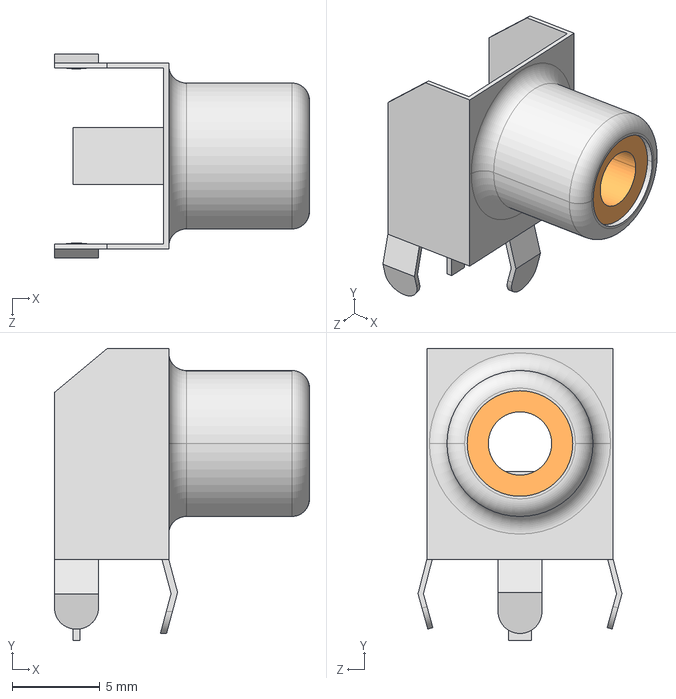
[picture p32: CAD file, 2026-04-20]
Cole - Pre and power Amp/poweramp/KiCADv6/RCJ-017/RCJ-017.step
14.5 x 16.6 x 11.6 mm

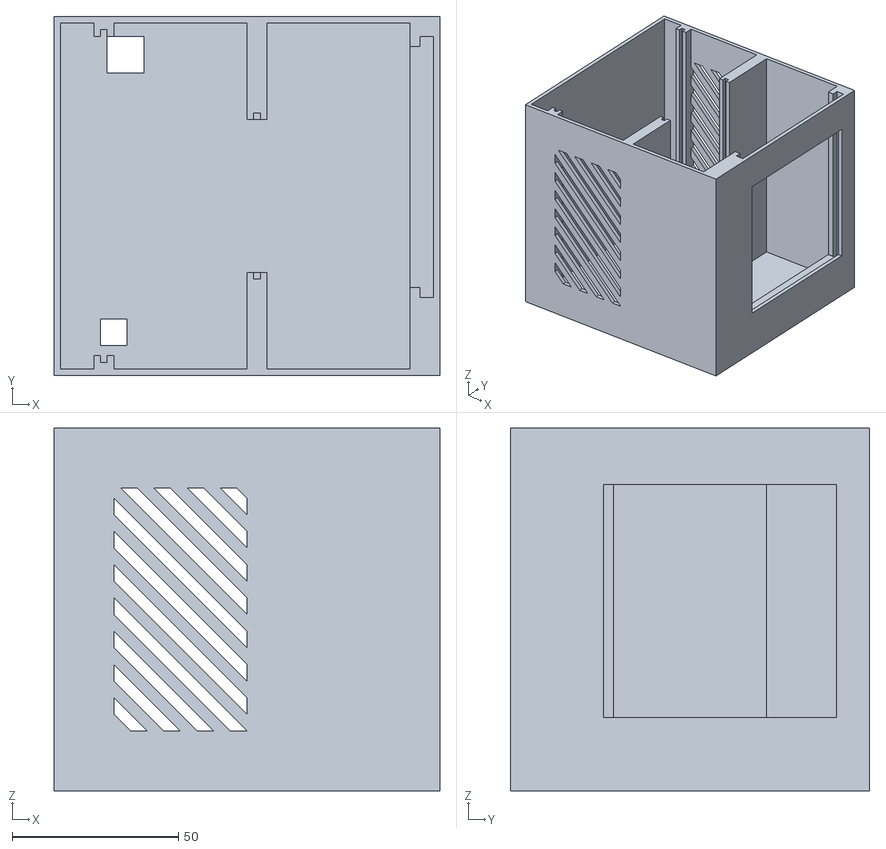
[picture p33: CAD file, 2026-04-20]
Microcontroller - Jonathan Roman/Casing/2026_tiamp_capstone_v2-box.stl
116.0 x 108.0 x 109.0

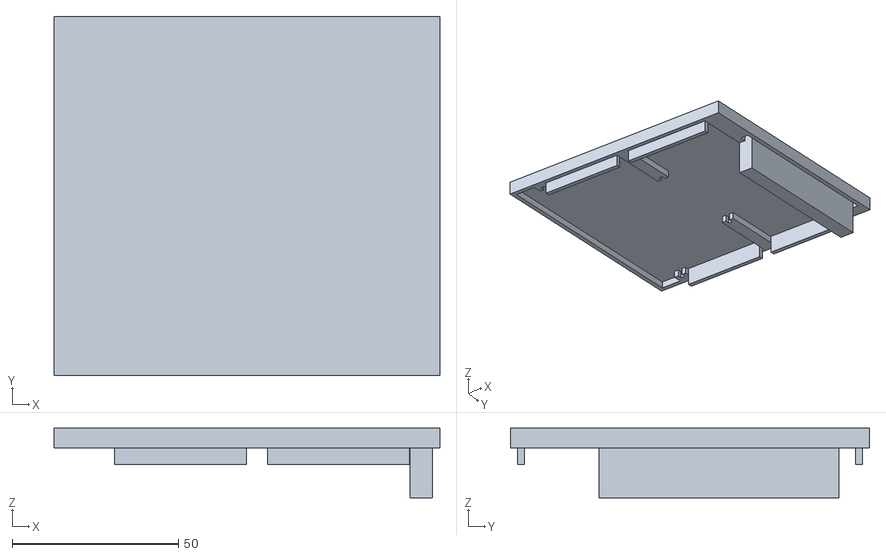
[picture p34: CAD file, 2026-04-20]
Microcontroller - Jonathan Roman/Casing/2026_tiamp_capstone_v2-lid.stl
116.0 x 108.0 x 21.0

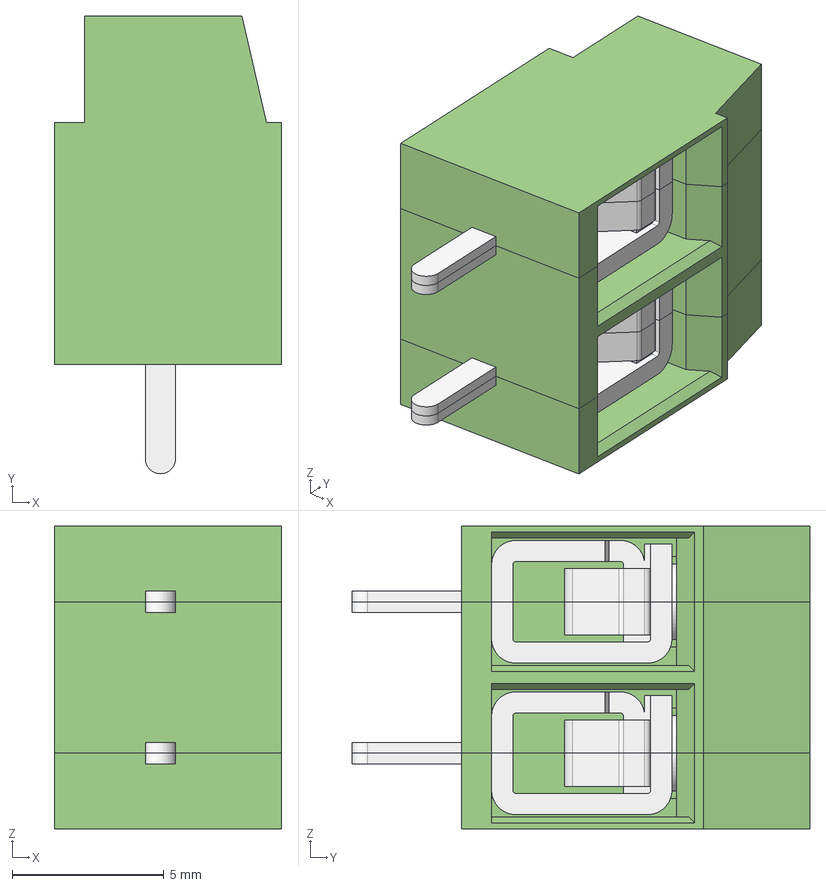
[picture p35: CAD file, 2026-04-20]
Cole - Pre and power Amp/aio_pcb/691137710002/691137710002.step
7.50 x 15.1 x 10.0 mm
MRT12P5_SX
MRT12P5_CNT
MRT12P5_DX

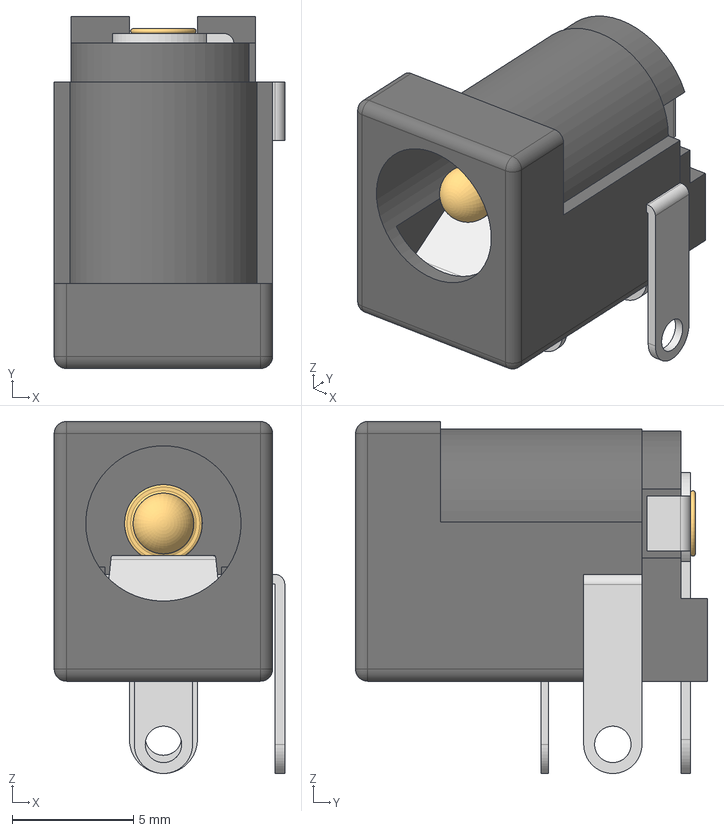
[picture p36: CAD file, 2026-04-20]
Cole - Pre and power Amp/aio_pcb/694108301002/694108301002.step
9.50 x 14.5 x 14.5 mm
6941xx301002
694108301002_PinContact
6941xx301002_Back
6941xx301002_PinContact2
6941xx301002_PinLame
6941xx301002_PinBis

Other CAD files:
Microcontroller - Jonathan Roman/Casing/2026_tiamp_capstone_v1.stl
Cole - Pre and power Amp/poweramp/691210910002/691210910002.step
Microcontroller - Jonathan Roman/Casing/2026_tiamp_capstone_v1-lid.stl

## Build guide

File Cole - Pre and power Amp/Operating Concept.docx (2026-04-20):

# 1. Operating Concept

## 1. Scope

The Amplifier board with wireless volume and EQ controls will act as an audio amplifier board. It will take a line-level signal, like those produced from a 3.5mm audio jack of a phone and pass the audio signal through several stages of preamplification, equalization, and amplification so that the signal can drive a 1W, 8Ω speaker. Additionally, there will be a mobile app that wirelessly controls along with the volume and the three band equalizer of this board. The three-band equalizer will allow the user to individually control the amplification of the low, mid, and high frequency audio signals to the user’s liking. For demonstration purposes, this system will be a low power (1 watt), mono audio only design. If scaled up, this design could be used to drive more powerful stereo speakers for music and audio playback.

## 2. Operational Description and Constraints

The Amplifier board with wireless volume and EQ controls will be a user-controlled audio amplification device. The user will connect their chosen line level signal, whether that be from a phone, MP3 player, video game console, etc. to the input side of the board. The user then can connect an 8Ω speaker to the output side of the board. Eight ohms is the input impedance of common non amplified speakers. The user will then connect the associated app on their phone to the board, which will control the amplification volume, and the user controlled three band equalization. Having an equalizer is a useful feature for those who need to increase a specific signal. It can be used to amplify speech over background music, or to change the sound of an instrument. The board will be powered from an off the shelf 5V power supply, which will be connected to the board through a DC power jack.

The resulting constraints from the operation of the device are:

The user must provide a line level audio signal (about 1V peak to peak).

The user must remain within range of the wireless controller to utilize the phone app.

An 8Ω speaker must be provided by the user to be used for playback.

The device is designed to provide 1W of power to an 8Ω speaker, which is considered low power. The user should not expect a high-volume level from the speaker.

If the user wants more power, then a higher impedance speaker, like headphones could be used as the output device.

The required input voltage is relatively low at 5V. If more power is wanted from the amplifier, then a high current draw could be expected from the DC supply.

## 3. System Description

This system’s design is achieved through four subsystems: amplification, wireless MCU/control, power supply, and mobile app. The amplification stage will take in a common line level (1V peak to peak) signal from the user’s chosen playback device. It will then pass it through two distinct amplification stages. The first stage is the “pre-amplification” stage. In this stage the signal will be attenuated in the user’s desired ways. This includes volume control and the control of the three-band equalization. The 3-band EQ will be achieved through a common topology that utilizes three op amps. Each band, and the volume will be controlled through digital potentiometers controlled by the MCU. The next stage will take this attenuated signal and amplify it with a high-power op amp designed to provide 1 watt to an 8Ω speaker. The power supply will take in the 5V given by an off the shelf “wall-wart” and use a series of buck and boost converters to provide the needed voltages throughout the design. It will be providing 3.3V to the MCU while providing 12V to the amplification circuitry. The MCU itself will be an ESP32 development board, which will have firmware written for it designed specifically to control the digital potentiometers used for mixing and volume control. The ESP32 will be providing a WIFI signal to the phone, which will connect to it to use the app written for control over this device. The final system is the app itself, which is an android app that will interface with the ESP32, and provide volume, and 3-band EQ control.

## 4. Modes of Operations

There will be two primary modes of operation, one where the board acts as a simple amplifier with volume control, and another where there is the option of a 3-band equalizer. The equalizer will be disabled by default, and only simple volume control will be available in the app. This mode is intended for users who are not interested in manual EQ control.

If the user choses to, they can enable the three-band equalizer. This will allow for the individual control over the level of amplification/attenuation for the three frequency ranges. The low frequencies will be the signals around 100Hz, the midranges are 500 to 1KHz, and the highs are around 8kHz to 10kHz. Equalizer levels are user preference, and they will have the freedom to control these signals over a wide range of amplification.

## 5. Users

Users of this system should be capable of two things: connecting a line-level signal to the board and connecting a speaker to the output. This item will be mass marketed to consumers as a low-cost audio amplifier with wireless EQ control. This item could also be marketed to companies that manufacture wireless speakers, as due to its low power requirements and inbuilt wireless control, it could act as an effective amplifier for a portable, battery powered speaker.

Users should also be familiar with the concept of EQ control, and how it affects an audio signal. If users are unaware or not interested in EQ control, the second mode of operation outlined above can be used instead, to provide users with simple volume control only.

## 6. Support

Support for this system will be provided in the form of a detailed user manual outlining the physical connections, power requirements, speaker and input requirements, and mobile device requirements. Since this product also has an associated app, this manual can be integrated as a “help” section in the app. The mobile app can also have a first-time walkthrough for new users, aiding with things like connecting to the MCU and EQ control.

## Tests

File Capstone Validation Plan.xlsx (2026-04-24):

Identifier | Test Name | Success Criteria | Methodology | Status | Responsible Engineer(s)
3.2.3.1 | Verify input signal levels | Based on research, standard line level signal is 1.4Vpeak, need to ensure this as this is what preamp is biased around | Connect 3.5mm audio cable to source computer, Measure peak voltages to ensure amp isn't being over or underdriven | Pass | Cole Keating
3.2.3.2 | Measure power amp heat dissipation | TPA3116 should not enter thermal protection during test | Place cooling solution on chip, power a 8 Ohm load for 30+ minutes without the FAULT pin on the IC going high (indicating thermal protection) | Pass | Cole Keating
3.2.3.3 | Verify preamp output signal levels | Preamp output should never exceed 3Vpeak - From MAX9744 datasheet. Signal at max gain should not exceed this | Make sure 0dB bias level is below 10dB of 3V. Set input signal to 1.4V at a mixer frequency. Move potentiometer for max gain, verify output does not exceed 3V peak on oscilloscope. | Pass | Cole Keating
3.2.3.4 | Verify power amp output signal level | Power amp output should be able to drive a 8 ohm speaker at 5W without clipping. | Place load on output, verify output levels do not clip. | Pass | Cole Keating
3.2.3.5 | Verify THD parameters | THD < 5% at 1WRMS, THD <0.1% at 0.1W RMS | Use FRA mode on oscilloscope while driving a 1W and 0.1W load. Record THD levels. | Pass | Cole Keating
3.2.3.6, 3.2.4.2 | Integration of MCU EQ Control | MCU is able to command digital potentiometer. Digital potentiometer controls preamp mixing, volume. | Connect digital potentiometers to pin headers on preamp. Run MCU test code that sweeps potentiometers. Verify digital potentiometer controls preamp, volume | Pass | Cole Keating Jonathan Roman
3.2.3.7 | Verify ideal gain setting | Need to find ideal ratio between volume level, current draw, THD, and thermal output. This is a subjective measure, will need to form consensus with team | Power amp has configurable gain set using resistor divider. Need to find ideal combination relating to signal levels coming from volume pot. | Pass | Cole Keating
3.2.3.8 | Verify gain/attenuation levels with 12V biasing | Each band should be able to boost/attenuate 10dB. | Set band to maximum/minimum of adjustment range. Use the FRA tool on oscilloscope to verify dBs of boost/attenuation. Repeat for all 6 possible levels. Max/Min of Low, Mid, High. Measure output waveform with signal generator connected. Output should not clip. | Pass | Cole Keating
3.2.2 | Verify Power levels | Based on research and simulations nothing in the circuit should exceed 2 Watts of power | Connect Power management subsystem to Power input and measure all outputs to make sure they are within the criteria | Pass | Braeden Murdock
3.2.2.1 | Verify input voltage levels | Each subsystem needs varous input voltage supplies which are 12V, 5V, and 3.3V. The power management subsystem should output all desired levels of voltage | Measure output voltages of power management subsytem when powered on, by measureing the connectors that would lead to the other subsystems that need the Voltages described previously | Pass | Braeden Murdock
3.2.2.2 | Verify input current | Each subsystem has current draw that needs to be matched for the system to work. These range from 16 mA, 0.5 A and 4mA | Set up load resistors that will have the required voltage draw and measure the current through each to make sure that the power management subsystem can match current requirements for each other subsystem | Pass | Braeden Murdock
3.2.4.1 | Verify Wireless Connection | MCU is able to connect wirelessly to a mobile device. Mobile Device is used to send signals translated by the MCU | Power the MCU with a 3.3V Source. Connect through a generic Bluetooth integration. Send and recieve signals | Pass | Jonathan Roman
3.2.4.1 | Verify Wireless Connection With Mobile App | MCU is able to connect wirelessly to the Mobile App subsystem. Mobile App is used to send signals translated by the MCU | Power the MCU with a 3.3V Source. Connect through integrated Mobile App. Recieve and output signals | Pass | Hoation Guan Jonathan Roman
3.2.4.2 | Verify Signal Translation | MCU correctly translates input signals to respective SPI output. | Connect wirelessly to the MCU. Send preset signal pairs and verify output | Pass | Jonathan Roman
3.2.4.2 | Verify PCB implementation | MCU behaves as expected on PCB implementation | Connect wirelessly to the PCB integrated MCU. Send preset signal pairs and verify output | Pass | Jonathan Roman
3.2.1.1 | Verify the user feedback | Ensure UI give an feedback when use adjust the app setting. | When sliding the control slider, a small prompt appears below indicating the change has been applied. Additionally, a touch effect is displayed when the slider is touched. | Pass | Haotian Guan
3.2.1.2 | Verify the login page | Ensure users can log in using their Google account or register by using the email. Confirm the firebase stored the accounts. | Use Firebase for Flutter to set up a login page with Google accounts. Click “Sign in as guest” to use the app immediately. | Pass | Haotian Guan
3.2.1.3 | Verify the BLE connection | Ensure standardized commands sent to the MCU via BLE | Using Flutter's flutter_blue_plus, find the Service UUID and Characteristic UUID of the MCU, and then the App sends 2 bytes [portal, value] to MCU, where portal select valume/bass/mid/treble and value is the user-selected level. | Pass | Haotian Guan Jonathan Roman
3.2.1.4 | Verify the BLE detector | Ensure the mobile app UI return to the connection page once disconnection with MCU | Returning back to connection page once the MCU disconnection with mobile app, and exceeding the notification will alert the user. | Pass | Haotian Guan
3.2.1.5 | Verify the background theme | Ensure the control background can be changed by using background selection botton | Add a UI for background selection in the control page, allowing users to choose between the white and black themes, or to load their own photos as the theme. | Pass | Haotian Guan

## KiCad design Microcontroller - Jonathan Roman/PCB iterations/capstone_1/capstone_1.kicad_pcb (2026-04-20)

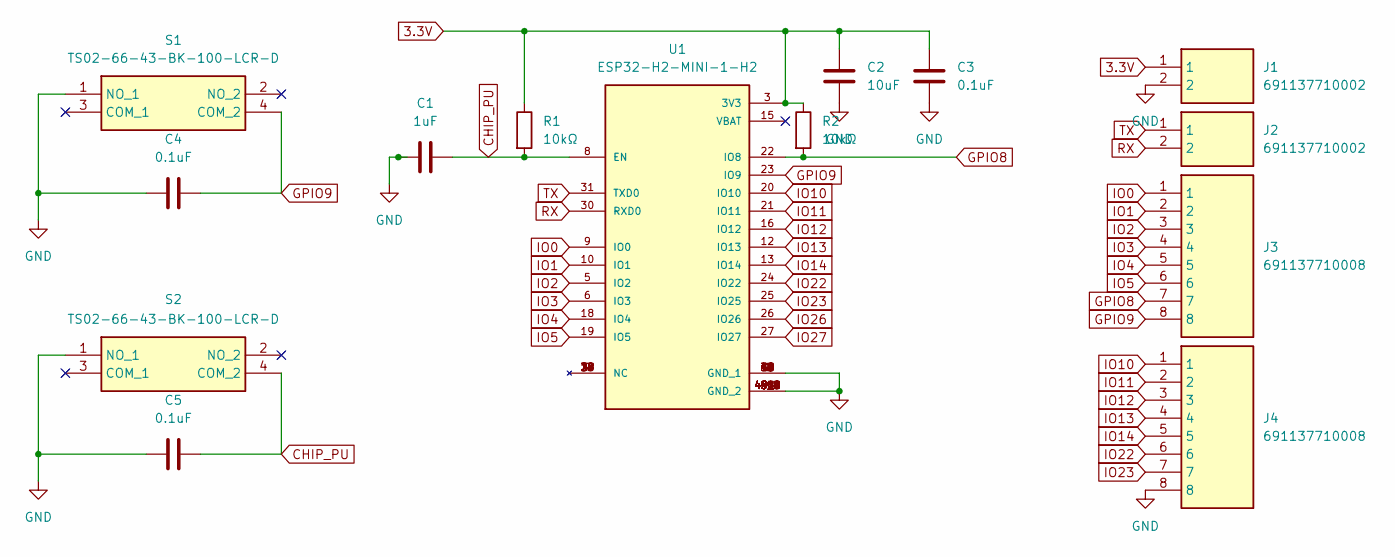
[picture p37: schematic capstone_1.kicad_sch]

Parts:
C1: 1uF; C_1206_3216Metric
C2: 10uF; C_1206_3216Metric
C3, C4, C5: 0.1uF; C_1206_3216Metric
J1, J2: 691137710002; SHDR2W70P0X500_1X2_1000X750X1160P; Mouser Part Number 710-691137710002
J3, J4: 691137710008; Mouser Part Number 710-691137710008
R1, R2: 10kΩ; R_1206_3216Metric
S1, S2: TS02-66-43-BK-100-LCR-D; TS026643BK100LCRD; Mouser Part Number 179-TS026643BK100LCR
U1: ESP32-H2-MINI-1-H2; MODULE_ESP32-H2-MINI-1-H2; PARTREV v0.5

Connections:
3.3V: C2.1, C3.1, J1.1, R1.1, R2.1, U1.3 (3V3)
CHIP_PU: C1.1, C5.2, R1.2, S2.4 (COM_2), U1.8 (EN)
GND: C1.2, C2.2, C3.2, C4.1, C5.1, J1.2, J4.8, S1.1 (NO_1), S2.1 (NO_1), U1.1 (GND_1), U1.2 (GND_1), U1.11 (GND_1), U1.14 (GND_1), U1.36 (GND_1), U1.37 (GND_1), U1.38 (GND_1), U1.39 (GND_1), U1.40 (GND_1), U1.41 (GND_1), U1.42 (GND_1), U1.43 (GND_1), U1.44 (GND_1), U1.45 (GND_1), U1.46 (GND_1), U1.47 (GND_2), U1.48 (GND_2), U1.49_1 (GND_2), U1.49_2 (GND_2), U1.49_3 (GND_2), U1.49_4 (GND_2), U1.49_5 (GND_2), U1.49_6 (GND_2), U1.49_7 (GND_2), U1.49_8 (GND_2), U1.49_9 (GND_2), U1.50 (GND_2), U1.51 (GND_2), U1.52 (GND_2), U1.53 (GND_2)
GPIO8: J3.7, R2.2, U1.22 (IO8)
GPIO9: C4.2, J3.8, S1.4 (COM_2), U1.23 (IO9)
IO0: J3.1, U1.9 (IO0)
IO1: J3.2, U1.10 (IO1)
IO2: J3.3, U1.5 (IO2)
IO3: J3.4, U1.6 (IO3)
IO4: J3.5, U1.18 (IO4)
IO5: J3.6, U1.19 (IO5)
IO10: J4.1, U1.20 (IO10)
IO11: J4.2, U1.21 (IO11)
IO12: J4.3, U1.16 (IO12)
IO13: J4.4, U1.12 (IO13)
IO14: J4.5, U1.13 (IO14)
IO22: J4.6, U1.24 (IO22)
IO23: J4.7, U1.25 (IO25)
IO26: U1.26 (IO26)
IO27: U1.27 (IO27)
RX: J2.2, U1.30 (RXD0)
TX: J2.1, U1.31 (TXD0)

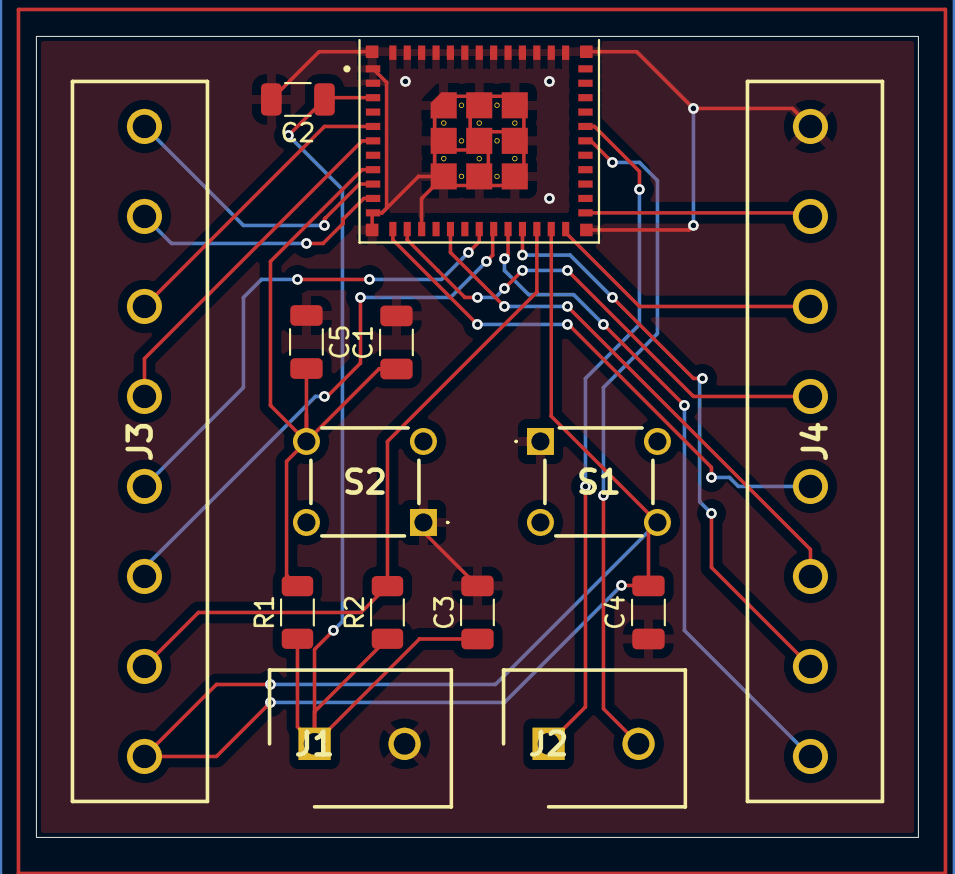
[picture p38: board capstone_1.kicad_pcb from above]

Board: 2 copper layers, 49.0 x 44.5 mm, 14 parts (0 on the bottom side), 20 nets.

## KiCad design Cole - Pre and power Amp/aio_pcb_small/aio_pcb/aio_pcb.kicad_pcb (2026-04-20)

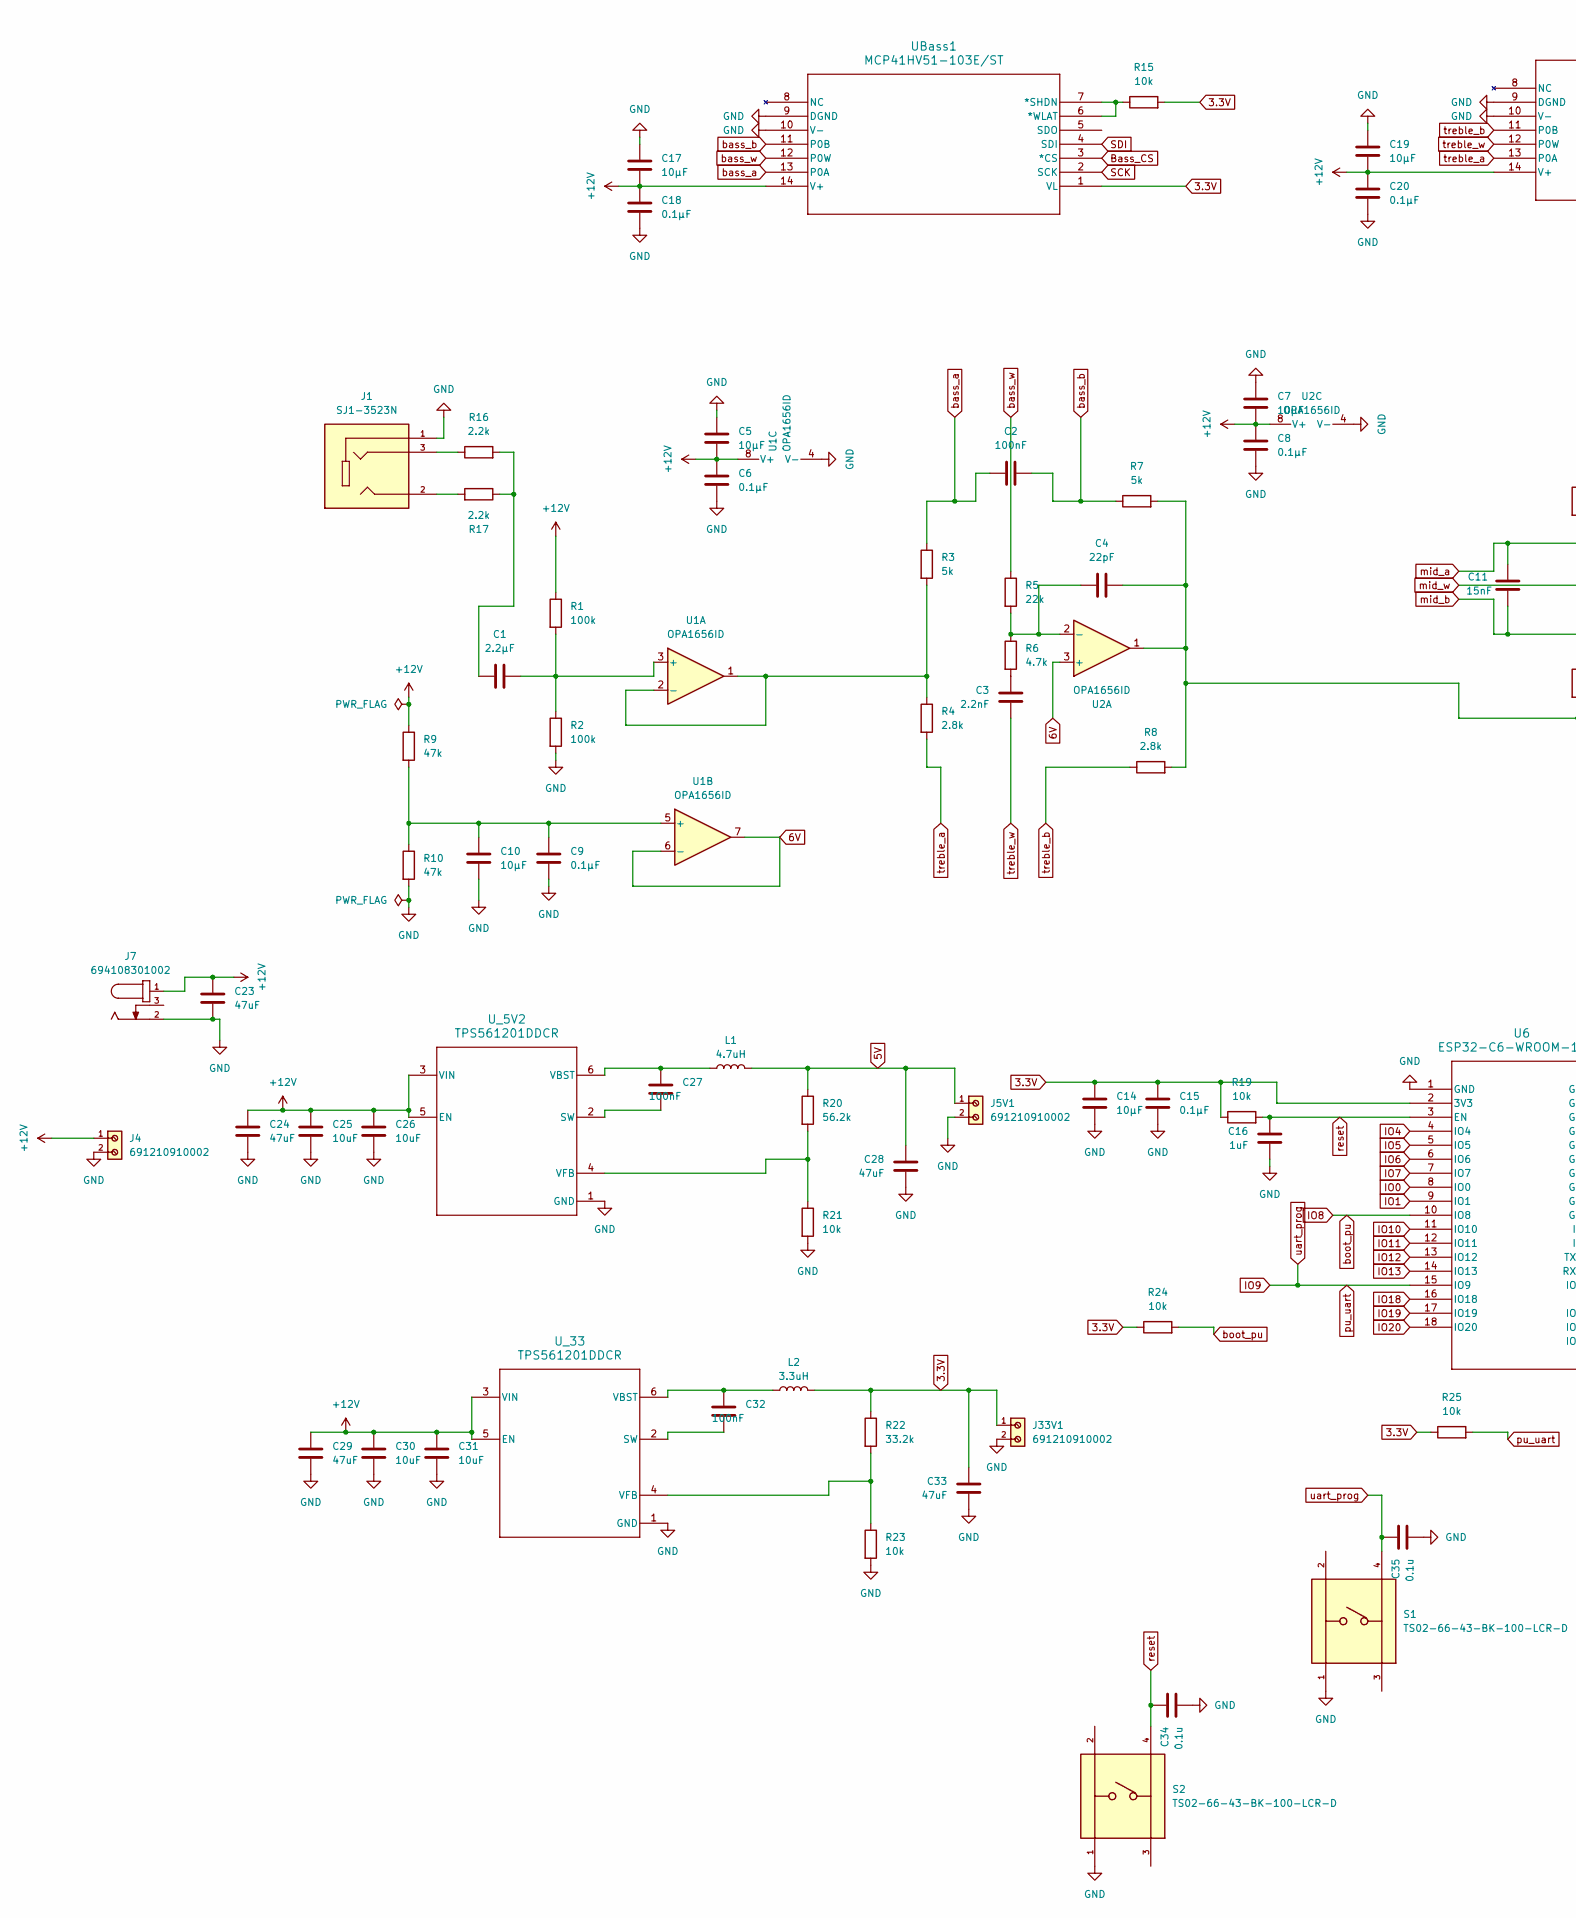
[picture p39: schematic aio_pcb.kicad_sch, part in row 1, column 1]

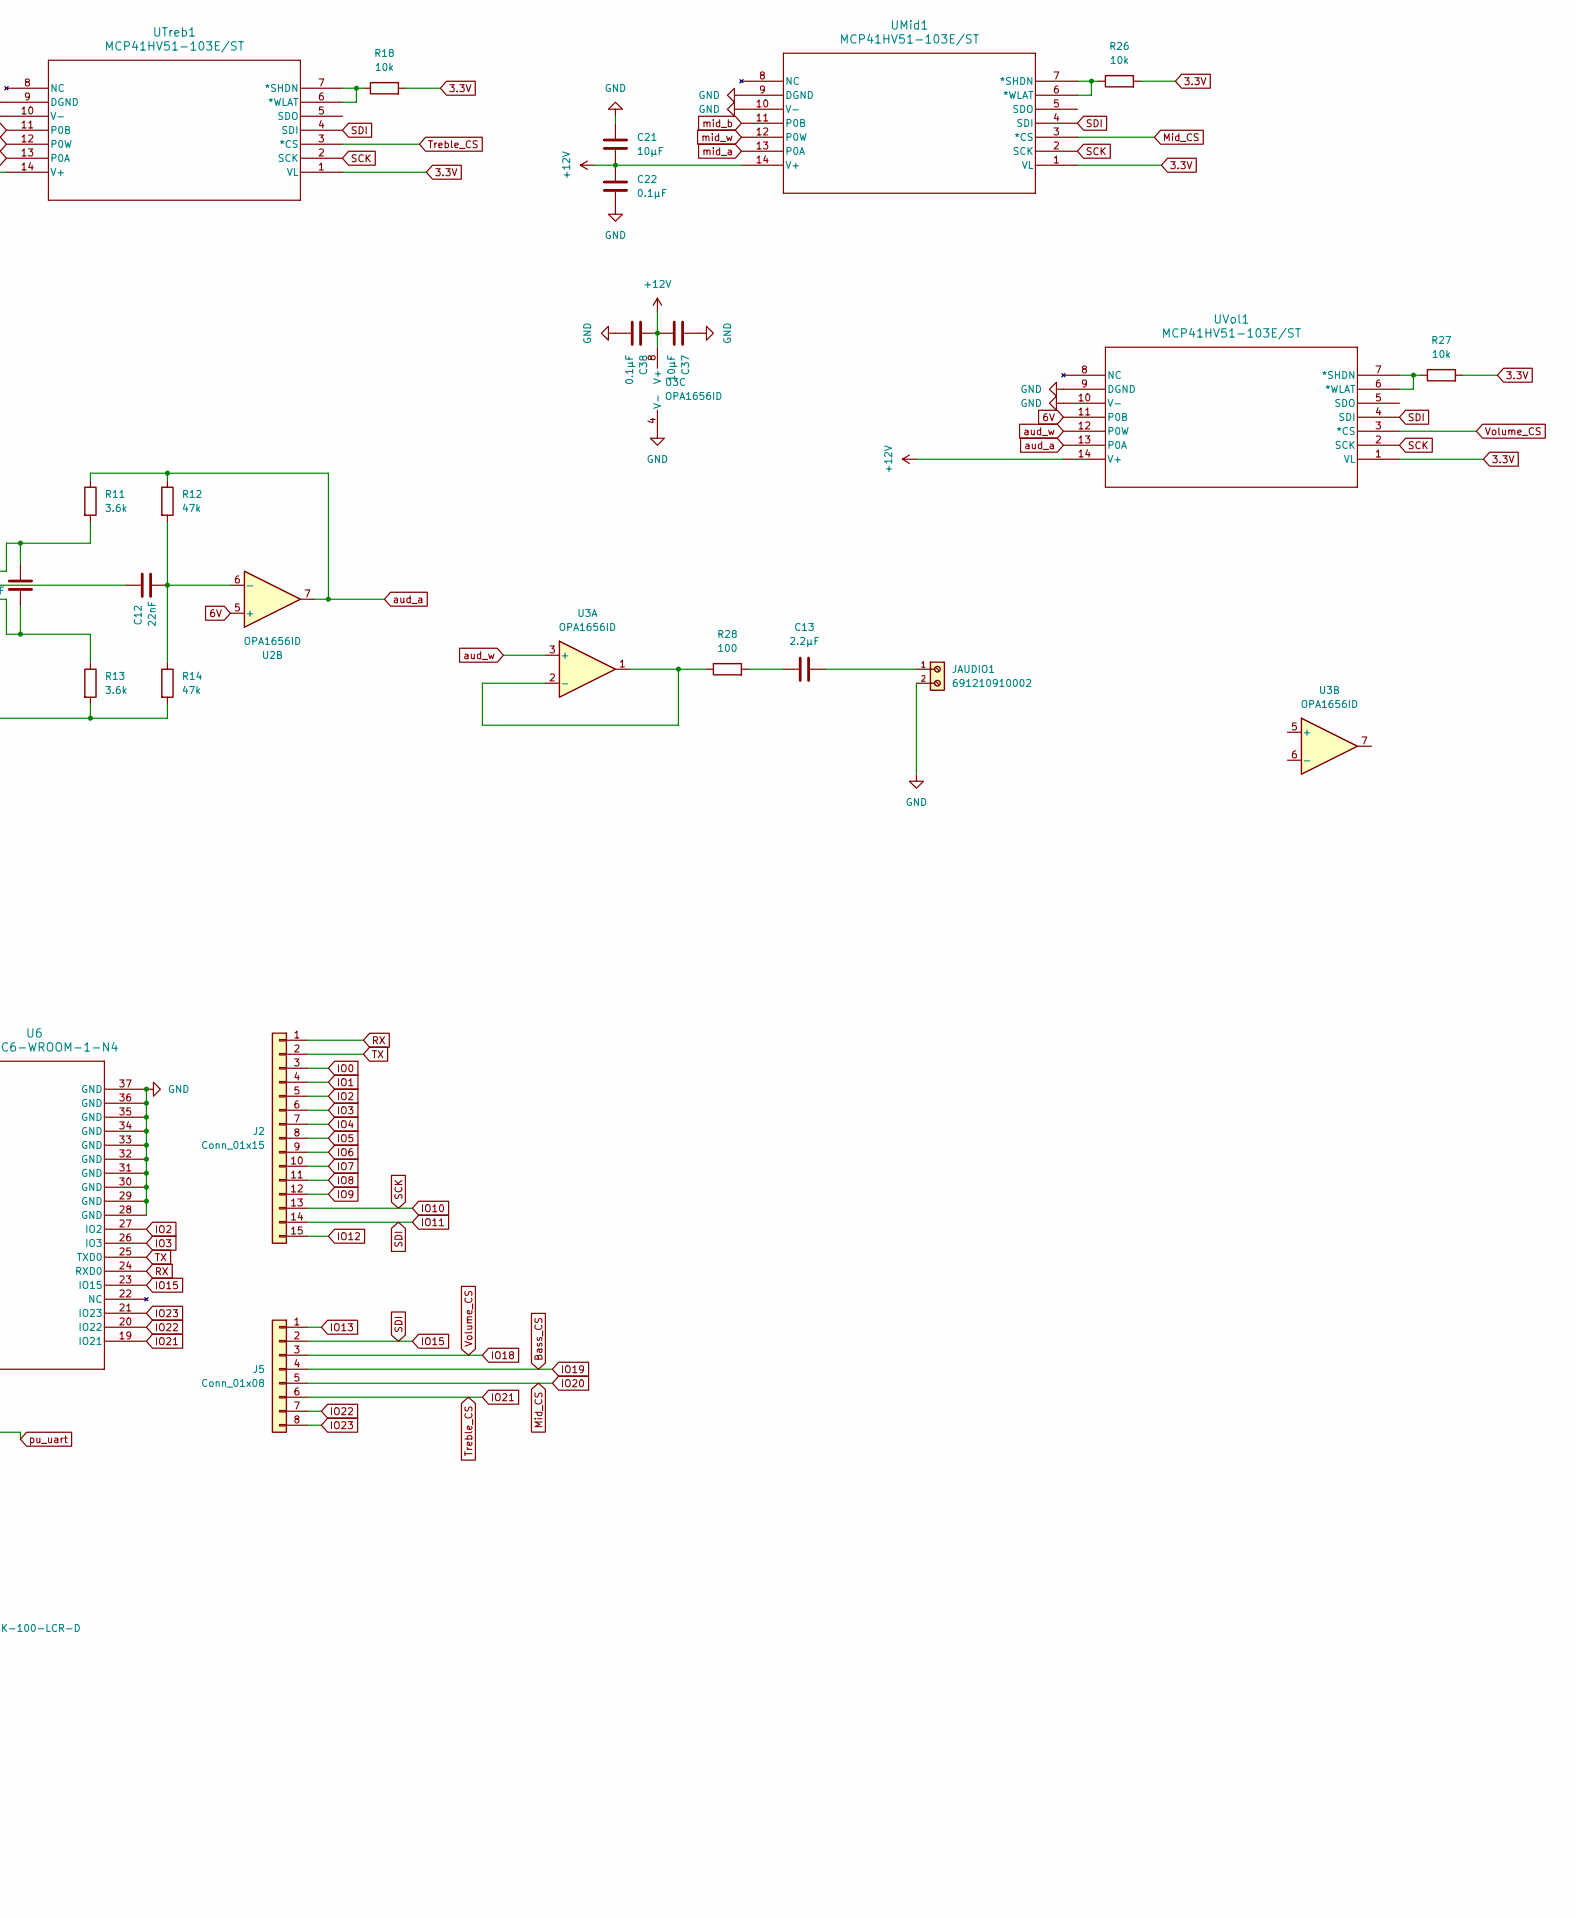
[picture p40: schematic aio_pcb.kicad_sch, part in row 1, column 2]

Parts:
C1, C13: 2.2μF; C_Rect_L19.0mm_W5.0mm_P15.00mm_MKS4
C2: 100nF; C_Rect_L7.2mm_W2.5mm_P5.00mm_FKS2_FKP2_MKS2_MKP2
C3: 2.2nF; C_Rect_L7.2mm_W2.5mm_P5.00mm_FKS2_FKP2_MKS2_MKP2
C4: 22pF; C_Disc_D3.0mm_W1.6mm_P2.50mm
C5, C7, C10, C14, C17, C19, C21, C37: 10μF; CP_Radial_D5.0mm_P2.00mm
C6, C8, C9, C15, C18, C20, C22, C38: 0.1μF; C_Disc_D3.0mm_W1.6mm_P2.50mm
C11: 15nF; C_Rect_L7.2mm_W2.5mm_P5.00mm_FKS2_FKP2_MKS2_MKP2
C12: 22nF; C_Rect_L7.2mm_W2.5mm_P5.00mm_FKS2_FKP2_MKS2_MKP2
C16: 1uF; C_Disc_D3.0mm_W1.6mm_P2.50mm
C23, C24, C28, C29, C33: 47uF; CP_Radial_D5.0mm_P2.00mm
C25, C26, C30, C31: 10uF; C_0805_2012Metric
C27, C32: 100nF; C_0603_1608Metric
C34, C35: 0.1u; C_1206_3216Metric
J1: SJ1-3523N; CUI_SJ1-3523N; PARTREV 1.05
J2: Conn_01x15; PinHeader_1x15_P2.54mm_Vertical
J4, J5V1, J33V1: 691210910002
J5: Conn_01x08; PinHeader_1x08_P2.54mm_Vertical
J7: 694108301002
JAUDIO1: 691210910002
L1: 4.7uH; L_1008_2520Metric
L2: 3.3uH; L_0805_2012Metric
R1, R2: 100k; R_1206_3216Metric
R3, R7: 5k; R_1206_3216Metric
R4, R8: 2.8k; R_1206_3216Metric
R5: 22k; R_1206_3216Metric
R6: 4.7k; R_1206_3216Metric
R9, R10, R12, R14: 47k; R_1206_3216Metric
R11, R13: 3.6k; R_1206_3216Metric
R15, R18, R19, R24, R25, R26, R27: 10k; R_1206_3216Metric
R16, R17: 2.2k; R_1206_3216Metric
R20: 56.2k; R_0603_1608Metric
R21, R23: 10k; R_0603_1608Metric
R22: 33.2k; R_0603_1608Metric
R28: 100; R_1206_3216Metric
S1, S2: TS02-66-43-BK-100-LCR-D; SW_TS02-66-43-BK-100-LCR-D; PARTREV 1.0
U1, U2, U3: OPA1656ID; SOIC-8_3.9x4.9mm_P1.27mm
U6: ESP32-C6-WROOM-1-N4; MOD28_ESP32-C6-WROOM-1_EXP
UBass1: MCP41HV51-103E/ST; TSSOP14_MC_MCH
UMid1: MCP41HV51-103E/ST; TSSOP14_MC_MCH
UTreb1: MCP41HV51-103E/ST; TSSOP14_MC_MCH
UVol1: MCP41HV51-103E/ST; TSSOP14_MC_MCH
U_5V2, U_33: TPS561201DDCR; DDC0006A_N

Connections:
3.3V: C14.2, C15.2, C33.1, J33V1.1, L2.2, R15.2, R18.2, R19.1, R22.1, R24.1, R25.1, R26.2, R27.2, U6.2 (3V3), UBass1.1 (VL), UMid1.1 (VL), UTreb1.1 (VL), UVol1.1 (VL)
5V: C28.1, J5V1.1, L1.2, R20.1
6V: U1.6 (-), U1.7, U2.3 (+), U2.5 (+), UVol1.11 (P0B)
+12V: C5.1, C6.2, C7.1, C8.2, C17.1, C18.2, C19.1, C20.2, C21.1, C22.2, C23.1, C24.1, C25.1, C26.1, C29.1, C30.1, C31.1, C37.1, C38.2, J4.1, J7.1, R1.1, R9.1, U1.8 (V+), U2.8 (V+), U3.8 (V+), UBass1.14 (V+), UMid1.14 (V+), UTreb1.14 (V+), UVol1.14 (V+), U_5V2.3 (VIN), U_5V2.5 (EN), U_33.3 (VIN), U_33.5 (EN)
Bass_CS: J5.4, U6.17 (IO19), UBass1.3 (*CS)
GND: C5.2, C6.1, C7.2, C8.1, C9.2, C10.2, C14.1, C15.1, C16.1, C17.2, C18.1, C19.2, C20.1, C21.2, C22.1, C23.2, C24.2, C25.2, C26.2, C28.2, C29.2, C30.2, C31.2, C33.2, C34.2, C35.2, C37.2, C38.1, J1.1, J4.2, J5V1.2, J7.2, J33V1.2, JAUDIO1.2, R2.2, R10.2, R21.2, R23.2, S1.1, S2.1, U1.4 (V-), U2.4 (V-), U3.4 (V-), U6.1 (GND), U6.28 (GND), U6.29 (GND), U6.30 (GND), U6.31 (GND), U6.32 (GND), U6.33 (GND), U6.34 (GND), U6.35 (GND), U6.36 (GND), U6.37 (GND), UBass1.9 (DGND), UBass1.10 (V-), UMid1.9 (DGND), UMid1.10 (V-), UTreb1.9 (DGND), UTreb1.10 (V-), UVol1.9 (DGND), UVol1.10 (V-), U_5V2.1 (GND), U_33.1 (GND)
IO0: J2.3, U6.8 (IO0)
IO1: J2.4, U6.9 (IO1)
IO2: J2.5, U6.27 (IO2)
IO3: J2.6, U6.26 (IO3)
IO4: J2.7, U6.4 (IO4)
IO5: J2.8, U6.5 (IO5)
IO6: J2.9, U6.6 (IO6)
IO7: J2.10, U6.7 (IO7)
IO8: J2.11, R24.2, U6.10 (IO8)
IO9: C35.1, J2.12, R25.2, S1.4, U6.15 (IO9)
IO10: J2.13, U6.11 (IO10), UBass1.2 (SCK), UMid1.2 (SCK), UTreb1.2 (SCK), UVol1.2 (SCK)
IO11: J2.14, J5.2, U6.12 (IO11), U6.23 (IO15), UBass1.4 (SDI), UMid1.4 (SDI), UTreb1.4 (SDI), UVol1.4 (SDI)
IO12: J2.15, U6.13 (IO12)
IO13: J5.1, U6.14 (IO13)
IO18: J5.3, U6.16 (IO18), UVol1.3 (*CS)
IO20: J5.5, U6.18 (IO20), UMid1.3 (*CS)
IO21: J5.6, U6.19 (IO21), UTreb1.3 (*CS)
IO22: J5.7, U6.20 (IO22)
IO23: J5.8, U6.21 (IO23)
unnamed: C1.1, R16.2, R17.1
unnamed: C3.2, R6.2
unnamed: C4.1, R7.2, R8.2, R13.2, R14.2, U2.1
unnamed: C13.1, R28.2
unnamed: C13.2, JAUDIO1.1
unnamed: J1.2, R17.2
unnamed: J1.3, R16.1
unnamed: C1.2, R1.2, R2.1, U1.3 (+)
unnamed: R3.2, R4.1, U1.1, U1.2 (-)
unnamed: C9.1, C10.1, R9.2, R10.1, U1.5 (+)
unnamed: C4.2, R5.2, R6.1, U2.2 (-)
unnamed: C12.1, R12.2, R14.1, U2.6 (-)
unnamed: R28.1, U3.1, U3.2 (-)
unnamed: R15.1, UBass1.6 (*WLAT), UBass1.7 (*SHDN)
unnamed: R26.1, UMid1.6 (*WLAT), UMid1.7 (*SHDN)
unnamed: R18.1, UTreb1.6 (*WLAT), UTreb1.7 (*SHDN)
unnamed: R27.1, UVol1.6 (*WLAT), UVol1.7 (*SHDN)
unnamed: C27.2, U_5V2.2 (SW)
unnamed: C27.1, L1.1, U_5V2.6 (VBST)
unnamed: R20.2, R21.1, U_5V2.4 (VFB)
unnamed: C32.2, U_33.2 (SW)
unnamed: C32.1, L2.1, U_33.6 (VBST)
unnamed: R22.2, R23.1, U_33.4 (VFB)
RX: J2.1, U6.24 (RXD0)
TX: J2.2, U6.25 (TXD0)
aud_a: R11.1, R12.1, U2.7, UVol1.13 (P0A)
aud_w: U3.3 (+), UVol1.12 (P0W)
bass_a: C2.1, R3.1, UBass1.13 (P0A)
bass_b: C2.2, R7.1, UBass1.11 (P0B)
bass_w: R5.1, UBass1.12 (P0W)
mid_a: C11.2, R11.2, UMid1.13 (P0A)
mid_b: C11.1, R13.1, UMid1.11 (P0B)
mid_w: C12.2, UMid1.12 (P0W)
reset: C16.2, C34.1, R19.2, S2.4, U6.3 (EN)
treble_a: R4.2, UTreb1.13 (P0A)
treble_b: R8.1, UTreb1.11 (P0B)
treble_w: C3.1, UTreb1.12 (P0W)

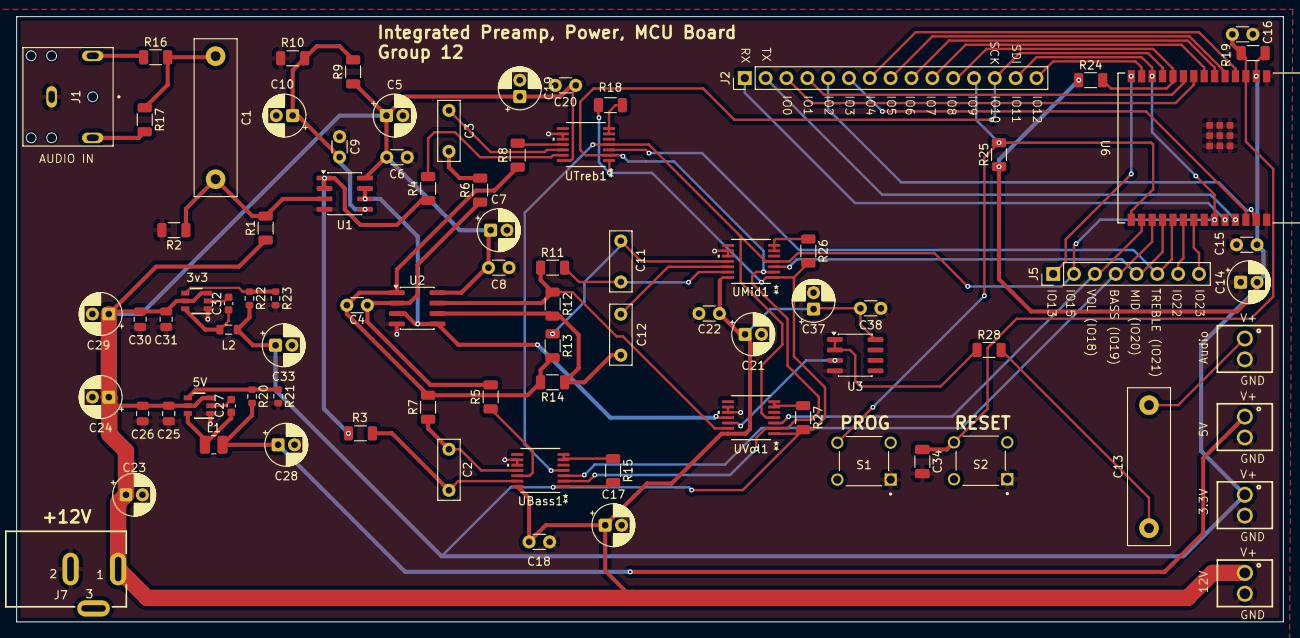
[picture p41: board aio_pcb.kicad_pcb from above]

Board: 2 copper layers, 154.4 x 73.8 mm, 86 parts (0 on the bottom side), 62 nets.

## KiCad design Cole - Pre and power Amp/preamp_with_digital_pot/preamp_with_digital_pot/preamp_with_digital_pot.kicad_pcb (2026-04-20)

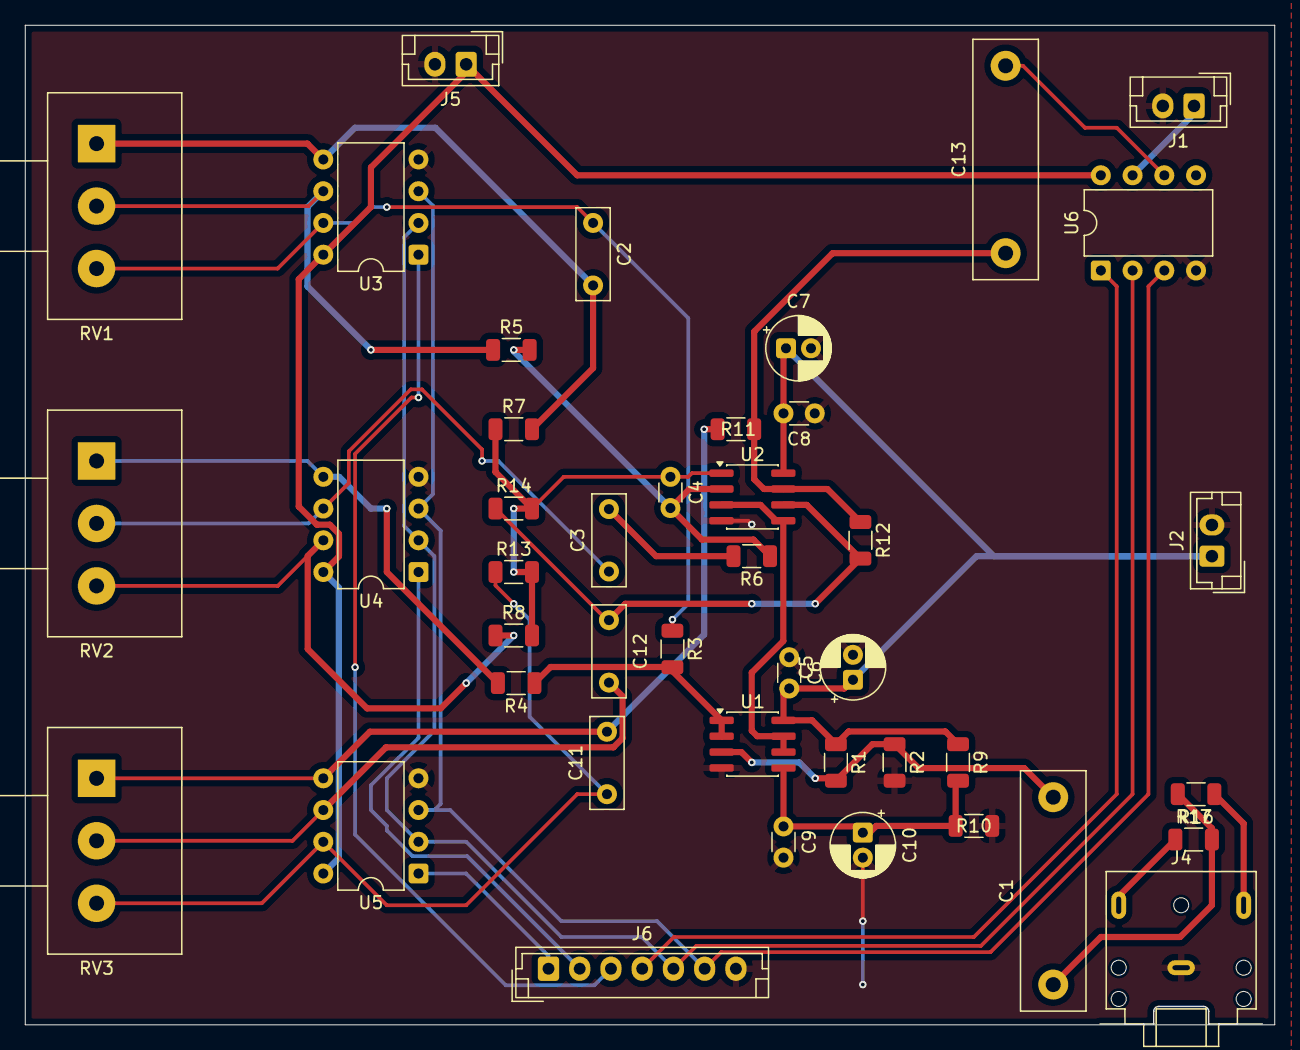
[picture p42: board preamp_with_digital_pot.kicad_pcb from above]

Board: 2 copper layers, 100.0 x 80.0 mm, 43 parts (0 on the bottom side), 32 nets.

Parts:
C1, C13: 2.2μF; C_Rect_L19.0mm_W5.0mm_P15.00mm_MKS4
C2: 100nF; C_Rect_L7.2mm_W2.5mm_P5.00mm_FKS2_FKP2_MKS2_MKP2
C3: 2.2nF; C_Rect_L7.2mm_W2.5mm_P5.00mm_FKS2_FKP2_MKS2_MKP2
C4: 22pF; C_Disc_D3.0mm_W1.6mm_P2.50mm
C5, C7, C10: 10μF; CP_Radial_D5.0mm_P2.00mm
C6, C8, C9: 0.1μF; C_Disc_D3.0mm_W1.6mm_P2.50mm
C11: 15nF; C_Rect_L7.2mm_W2.5mm_P5.00mm_FKS2_FKP2_MKS2_MKP2
C12: 22nF; C_Rect_L7.2mm_W2.5mm_P5.00mm_FKS2_FKP2_MKS2_MKP2
J1, J2, J5: Conn_01x02; JST_EH_B2B-EH-A_1x02_P2.50mm_Vertical
J4: AudioJack3; Jack_3.5mm_CUI_SJ1-3523N_Horizontal
J6: Conn_01x07; JST_EH_B7B-EH-A_1x07_P2.50mm_Vertical
R1, R2: 100k; R_1206_3216Metric
R3, R7: 5k; R_1206_3216Metric
R4, R8: 2.8k; R_1206_3216Metric
R5: 22k; R_1206_3216Metric
R6: 4.7k; R_1206_3216Metric
R9, R10, R12, R14: 47k; R_1206_3216Metric
R11, R13: 3.6k; R_1206_3216Metric
R16, R17: 2.2k; R_1206_3216Metric
RV1, RV2, RV3: R_Potentiometer; Potentiometer_Alps_RK163_Single_Horizontal
U1, U2: OPA1656ID; SOIC-8_3.9x4.9mm_P1.27mm
U3, U4, U5, U6: MCP4131-xxxx-P; DIP-8_W7.62mm

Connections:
+3.3V: J5.1, U3.8 (V_{DD}), U4.8 (V_{DD}), U5.8 (V_{DD}), U6.8 (V_{DD})
+6V: U1.6 (-), U1.7, U2.3 (+), U2.5 (+)
+12V: C5.1, C6.2, C7.1, C8.2, J2.1, R1.1, R9.1, U1.8 (V+), U2.8 (V+)
CS_BASS: J6.3, U3.1 (~CS)
CS_MID: J6.1, U5.1 (~CS)
CS_TREBLE: J6.2, U4.1 (~CS)
GND: C5.2, C6.1, C7.2, C8.1, C9.2, C10.2, J1.2, J2.2, J4.S, J5.2, J6.7, R2.2, R10.2, U1.4 (V-), U2.4 (V-), U3.4 (V_{SS}), U4.4 (V_{SS}), U5.4 (V_{SS}), U6.4 (V_{SS})
unnamed: C1.1, R16.2, R17.2
unnamed: C3.2, R6.2
unnamed: C4.1, R7.1, R8.2, R13.2, R14.2, U2.1
unnamed: C13.1, R11.2, R12.1, U2.7
unnamed: J1.1, U6.7 (P0B)
unnamed: J4.R, R17.1
unnamed: J4.T, R16.1
unnamed: C1.2, R1.2, R2.1, U1.3 (+)
unnamed: R3.2, R4.1, U1.1, U1.2 (-)
unnamed: C9.1, C10.1, R9.2, R10.1, U1.5 (+)
unnamed: C4.2, R5.2, R6.1, U2.2 (-)
unnamed: C12.1, R12.2, R14.1, U2.6 (-)
unnamed: C2.2, R7.2, RV1.1, U3.5 (P0A)
unnamed: C2.1, R3.1, RV1.3, U3.7 (P0B)
unnamed: R5.1, RV1.2, U3.6 (P0W)
unnamed: R4.2, RV2.1, U4.5 (P0A)
unnamed: R8.1, RV2.3, U4.7 (P0B)
unnamed: C3.1, RV2.2, U4.6 (P0W)
unnamed: C11.2, R11.1, RV3.1, U5.5 (P0A)
unnamed: C11.1, R13.1, RV3.3, U5.7 (P0B)
unnamed: C12.2, RV3.2, U5.6 (P0W)
unnamed: C13.2, U6.6 (P0W)
SCK: J6.5, U3.2 (SCK), U4.2 (SCK), U5.2 (SCK), U6.2 (SCK)
SDI: J6.6, U3.3 (SDI/SDO), U4.3 (SDI/SDO), U5.3 (SDI/SDO), U6.3 (SDI/SDO)
VOL: J6.4, U6.1 (~CS)

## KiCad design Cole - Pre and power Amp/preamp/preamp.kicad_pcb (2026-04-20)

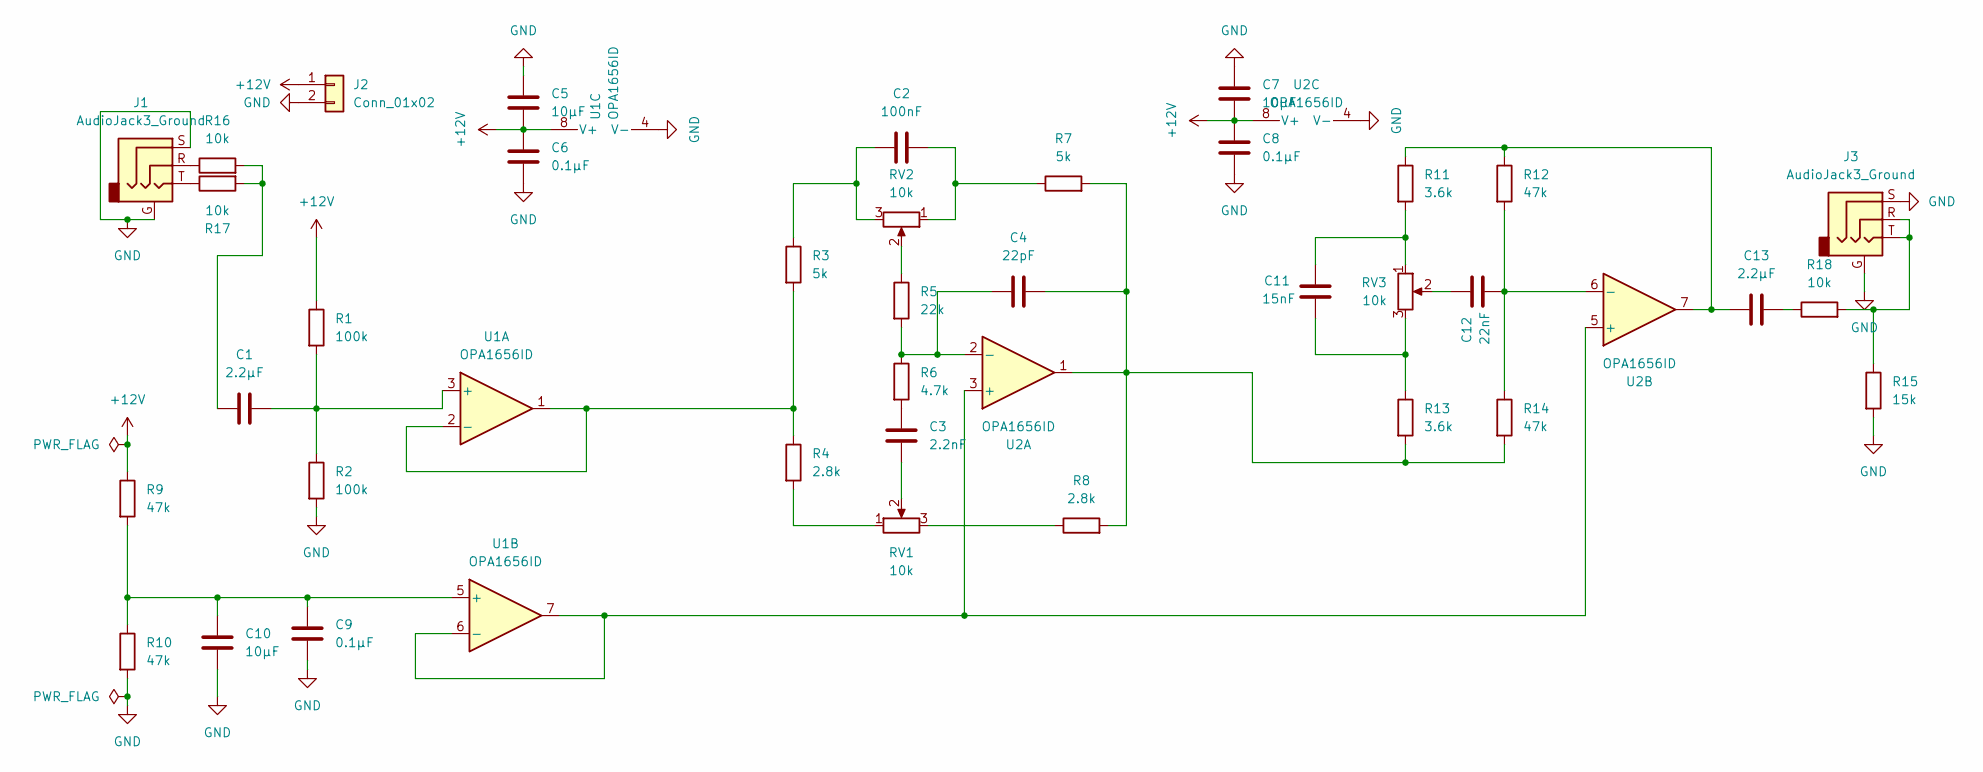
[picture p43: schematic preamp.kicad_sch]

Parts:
C1, C13: 2.2μF; C_Rect_L19.0mm_W5.0mm_P15.00mm_MKS4
C2: 100nF; C_Rect_L7.2mm_W2.5mm_P5.00mm_FKS2_FKP2_MKS2_MKP2
C3: 2.2nF; C_Rect_L7.2mm_W2.5mm_P5.00mm_FKS2_FKP2_MKS2_MKP2
C4: 22pF; C_Disc_D3.0mm_W1.6mm_P2.50mm
C5, C7, C10: 10μF; CP_Radial_D5.0mm_P2.00mm
C6, C8, C9: 0.1μF; C_Disc_D3.0mm_W1.6mm_P2.50mm
C11: 15nF; C_Rect_L7.2mm_W2.5mm_P5.00mm_FKS2_FKP2_MKS2_MKP2
C12: 22nF; C_Rect_L7.2mm_W2.5mm_P5.00mm_FKS2_FKP2_MKS2_MKP2
J1, J3: AudioJack3_Ground; Jack_3.5mm_CUI_SJ1-3523N_Horizontal
J2: Conn_01x02; JST_XH_B2B-XH-A_1x02_P2.50mm_Vertical
R1, R2: 100k; R_Axial_DIN0207_L6.3mm_D2.5mm_P7.62mm_Horizontal
R3, R7: 5k; R_Axial_DIN0207_L6.3mm_D2.5mm_P7.62mm_Horizontal
R4, R8: 2.8k; R_Axial_DIN0207_L6.3mm_D2.5mm_P7.62mm_Horizontal
R5: 22k; R_Axial_DIN0207_L6.3mm_D2.5mm_P7.62mm_Horizontal
R6: 4.7k; R_Axial_DIN0207_L6.3mm_D2.5mm_P7.62mm_Horizontal
R9, R10, R12, R14: 47k; R_Axial_DIN0207_L6.3mm_D2.5mm_P7.62mm_Horizontal
R11, R13: 3.6k; R_Axial_DIN0207_L6.3mm_D2.5mm_P7.62mm_Horizontal
R15: 15k; R_Axial_DIN0207_L6.3mm_D2.5mm_P7.62mm_Horizontal
R16, R17, R18: 10k; R_Axial_DIN0207_L6.3mm_D2.5mm_P7.62mm_Horizontal
RV1, RV2, RV3: 10k; Potentiometer_Alps_RK163_Single_Horizontal
U1, U2: OPA1656ID; SOIC-8_3.9x4.9mm_P1.27mm

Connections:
+12V: C5.1, C6.2, C7.1, C8.2, J2.1, R1.1, R9.1, U1.8 (V+), U2.8 (V+)
GND: C5.2, C6.1, C7.2, C8.1, C9.2, C10.2, J1.G, J1.S, J2.2, J3.G, J3.S, R2.2, R10.2, R15.2, U1.4 (V-), U2.4 (V-)
unnamed: C1.1, R16.2, R17.2
unnamed 3: C2.1, R3.1, RV2.3; also elsewhere on the board
unnamed 4: C2.2, R7.1, RV2.1; also elsewhere on the board
unnamed 5: C3.1, RV1.2; also elsewhere on the board
unnamed: C3.2, R6.2
unnamed: C4.1, R7.2, R8.2, R13.2, R14.2, U2.1
unnamed 8: C11.1, R13.1, RV3.3; also elsewhere on the board
unnamed 9: C11.2, R11.2, RV3.1; also elsewhere on the board
unnamed 10: C12.2, RV3.2; also elsewhere on the board
unnamed: C13.1, R11.1, R12.1, U2.7
unnamed: C13.2, R18.1
unnamed: J1.R, R16.1
unnamed: J1.T, R17.1
unnamed: J3.R, J3.T, R15.1, R18.2
unnamed 16: R4.2, RV1.1; also elsewhere on the board
unnamed 17: R5.1, RV2.2; also elsewhere on the board
unnamed 18: R8.1, RV1.3; also elsewhere on the board
unnamed: C1.2, R1.2, R2.1, U1.3 (+)
unnamed: R3.2, R4.1, U1.1, U1.2 (-)
unnamed: C9.1, C10.1, R9.2, R10.1, U1.5 (+)
unnamed: U1.6 (-), U1.7, U2.3 (+), U2.5 (+)
unnamed: C4.2, R5.2, R6.1, U2.2 (-)
unnamed: C12.1, R12.2, R14.1, U2.6 (-)

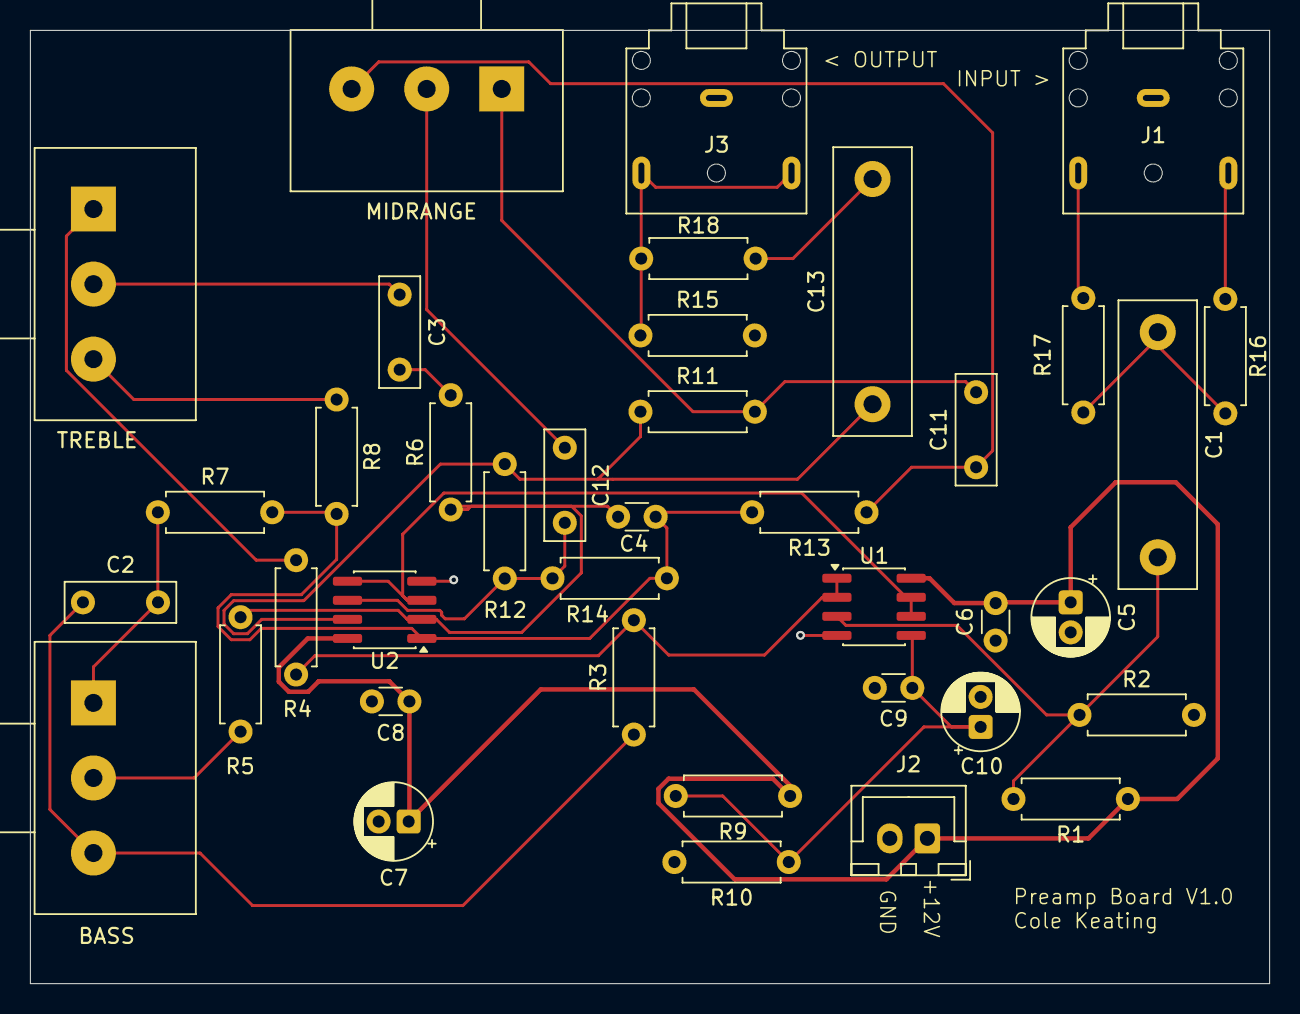
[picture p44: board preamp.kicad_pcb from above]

Board: 2 copper layers, 82.5 x 63.5 mm, 39 parts (0 on the bottom side), 25 nets.

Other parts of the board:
BASS: 10k; Potentiometer_Alps_RK163_Single_Horizontal
MIDRANGE: 10k; Potentiometer_Alps_RK163_Single_Horizontal
TREBLE: 10k; Potentiometer_Alps_RK163_Single_Horizontal

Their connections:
unnamed 3: BASS.3; also elsewhere on the board
unnamed 4: BASS.1; also elsewhere on the board
unnamed 5: TREBLE.2; also elsewhere on the board
unnamed 8: MIDRANGE.3; also elsewhere on the board
unnamed 9: MIDRANGE.1; also elsewhere on the board
unnamed 10: MIDRANGE.2; also elsewhere on the board
unnamed 16: TREBLE.1; also elsewhere on the board
unnamed 17: BASS.2; also elsewhere on the board
unnamed 18: TREBLE.3; also elsewhere on the board

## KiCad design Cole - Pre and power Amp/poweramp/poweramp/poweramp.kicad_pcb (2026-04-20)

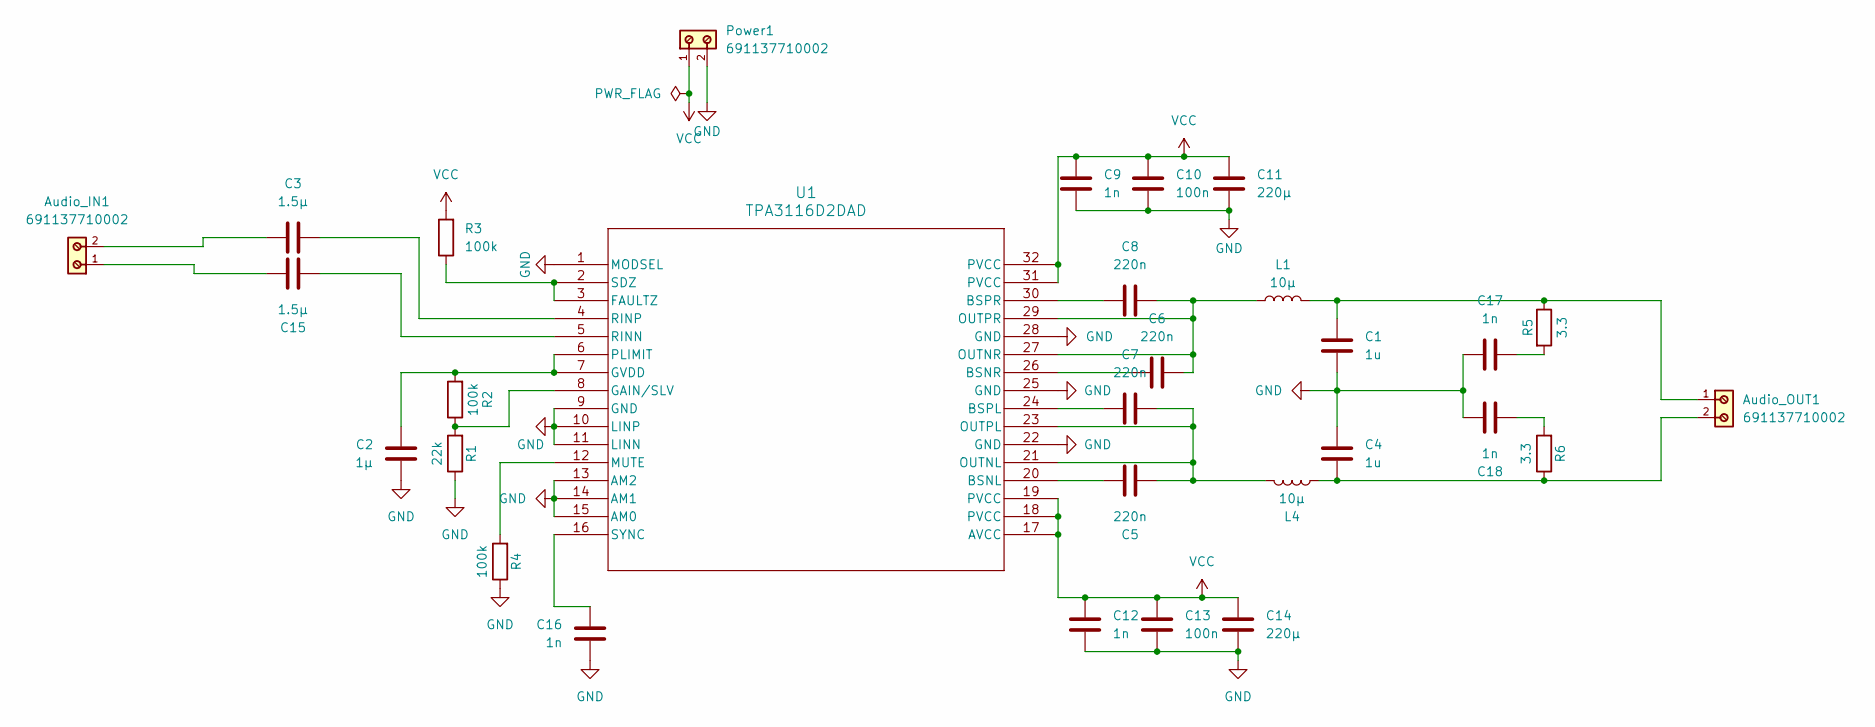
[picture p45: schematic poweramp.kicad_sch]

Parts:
Audio_IN1: 691137710002
Audio_OUT1: 691137710002
C1, C4: 1u; C_1206_3216Metric
C2: 1μ; C_1206_3216Metric
C3, C15: 1.5μ; C_Rect_L19.0mm_W5.0mm_P15.00mm_MKS4
C5, C6, C7, C8: 220n; C_1206_3216Metric
C9, C12, C16, C17, C18: 1n; C_1206_3216Metric
C10, C13: 100n; C_1206_3216Metric
C11, C14: 220μ; CP_Radial_D6.3mm_P2.50mm
L1, L4: 10μ; L_TDK_VLS6045EX_VLS6045AF
Power1: 691137710002
R1: 22k; R_Axial_DIN0207_L6.3mm_D2.5mm_P10.16mm_Horizontal
R2: 100k; R_Axial_DIN0207_L6.3mm_D2.5mm_P10.16mm_Horizontal
R3, R4: 100k; R_1206_3216Metric
R5, R6: 3.3; R_Axial_DIN0207_L6.3mm_D2.5mm_P10.16mm_Horizontal
U1: TPA3116D2DAD; DAD32_TEX

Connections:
GND: C1.2, C2.2, C4.2, C9.2, C10.2, C11.2, C12.2, C13.2, C14.2, C16.2, C17.1, C18.1, Power1.2, R1.1, R4.1, U1.1 (MODSEL), U1.9 (GND), U1.10 (LINP), U1.11 (LINN), U1.13 (AM2), U1.14 (AM1), U1.15 (AM0), U1.22 (GND), U1.25 (GND), U1.28 (GND)
unnamed: Audio_IN1.1, C15.1
unnamed: Audio_IN1.2, C3.1
unnamed: Audio_OUT1.1, C1.1, L1.2, R5.1
unnamed: Audio_OUT1.2, C4.1, L4.2, R6.1
unnamed: C17.2, R5.2
unnamed: C18.2, R6.2
unnamed: C5.2, U1.20 (BSNL)
unnamed: C6.2, U1.26 (BSNR)
unnamed: C7.2, U1.24 (BSPL)
unnamed: C8.2, U1.30 (BSPR)
unnamed: R3.1, U1.2 (SDZ), U1.3 (FAULTZ)
unnamed: R1.2, R2.1, U1.8 (GAIN/SLV)
unnamed: C2.1, R2.2, U1.6 (PLIMIT), U1.7 (GVDD)
unnamed: R4.2, U1.12 (MUTE)
unnamed: C5.1, C7.1, L4.1, U1.21 (OUTNL), U1.23 (OUTPL)
unnamed: C6.1, C8.1, L1.1, U1.27 (OUTNR), U1.29 (OUTPR)
unnamed: C15.2, U1.5 (RINN)
unnamed: C3.2, U1.4 (RINP)
unnamed: C16.1, U1.16 (SYNC)
VCC: C9.1, C10.1, C11.1, C12.1, C13.1, C14.1, Power1.1, R3.2, U1.17 (AVCC), U1.18 (PVCC), U1.19 (PVCC), U1.31 (PVCC), U1.32 (PVCC)

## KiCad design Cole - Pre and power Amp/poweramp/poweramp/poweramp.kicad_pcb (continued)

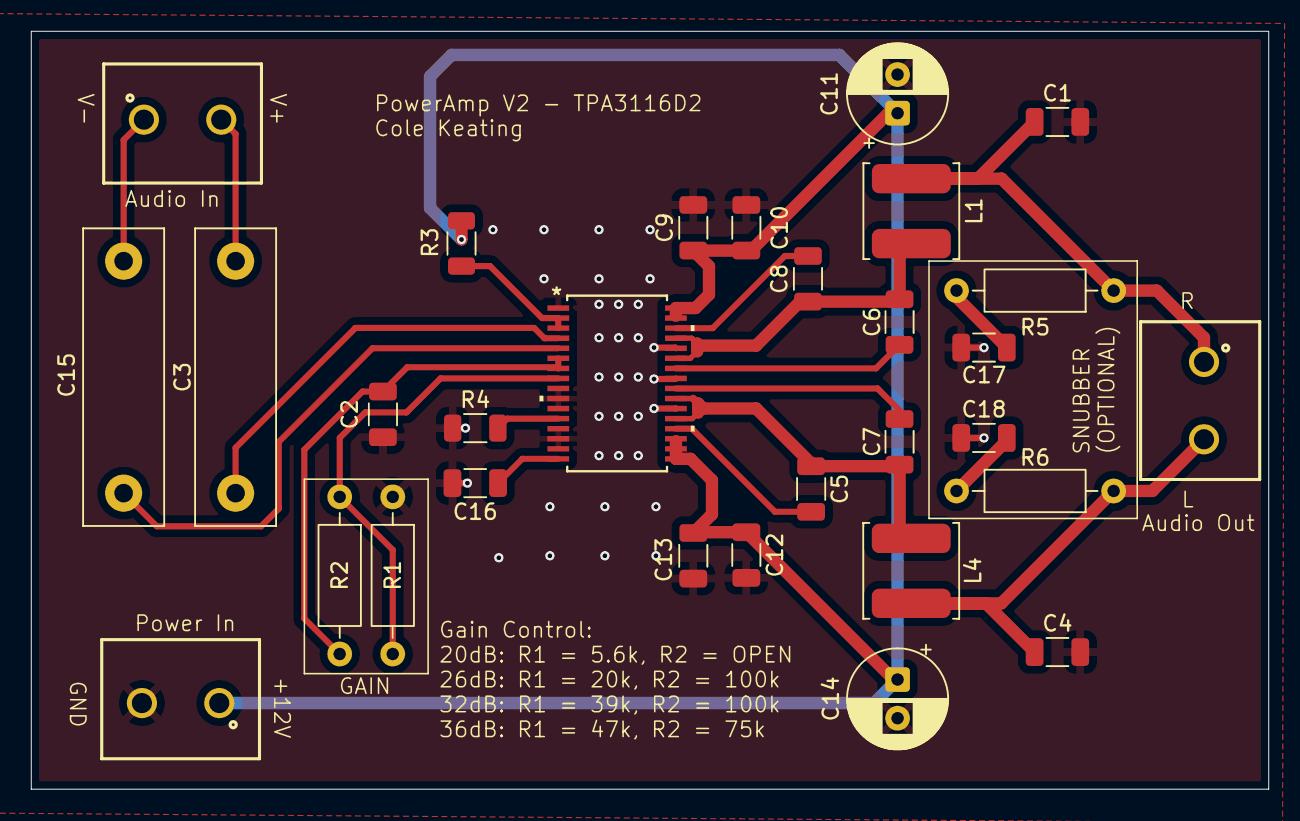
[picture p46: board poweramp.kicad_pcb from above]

Board: 2 copper layers, 80.0 x 49.0 mm, 30 parts (0 on the bottom side), 21 nets.

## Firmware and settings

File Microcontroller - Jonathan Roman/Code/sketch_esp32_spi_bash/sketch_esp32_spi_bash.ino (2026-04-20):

#include <BLEDevice.h>
#include <BLEServer.h>
#include <BLEUtils.h>

// See the following for generating UUIDs:
// https://www.uuidgenerator.net/
/*
UUIDs are used for server, service, and characteristic tracking and connection across multiple devices using BLE. 
The UUIDs below were used to declare characteristics, both for the final project and for BLE testing
*/
#define SERVICE_UUID         "94fa7d4e-136a-43d2-9f08-c8f296530110"
#define CHARACTERISTIC_RECEIVE0 "df170f02-3641-4594-806d-c113a27ce6cb"
#define CHARACTERISTIC_RECEIVE1 "cda5747e-5862-4196-be75-6d5c2b9fa72d"
#define CHARACTERISTIC_UUID1 "762c4a12-fbae-4904-872a-56373c871e69"
#define CHARACTERISTIC_UUID2 "c74e219d-d204-4e2d-87e5-4c9a7636438b"
#define CHARACTERISTIC_UUID3 "27af974a-50c8-4d4c-bd25-d9f872e59dff"
#define CHARACTERISTIC_UUID4 "a8b3ec2f-2c93-46d9-a71b-2e5d7448693b"
#define CHARACTERISTIC_UUID5 "bfd96262-5124-46c8-b412-c316098f26bd"
#define CHARACTERISTIC_UUID6 "d285491d-331f-4f17-95a3-103b2a072304"


/*The variables below were used for verification and testing through a BLE scanner app*/
//The pointer below was used for initial testing, to verify the code used to translate BLE signals to data changes and SPI sends
BLECharacteristic *LastChangedPort = nullptr;                //*_UUID5
//The pointer array used below was used to organize Volume and EQ control and verifying their states, organizing it as an array that is easily translatable to input data
BLECharacteristic *PortStates[4];                         //*_UUID1 -> //*_UUID4
//The pointer below was used for verification of signal translation, so that the input matches the output value
BLECharacteristic *SPI_Received = nullptr;                   //*_UUID6
                                                          //*_Recieved* is used for DataIn and write interfacing

//Sets up SPI protocol
#include <SPI.h>

// Define ALternate Pins to use non-standard GPIO pins for SPI bus
#define SPI_MISO  15      //Used to test SPI output, unneeded for implementation
#define SPI_MOSI  11      //Databus for SPI send
#define SPI_SCLK  10       //Clock used for SPI send
#define SPI_SS1   18      //Enable pin 1 (volume)
#define SPI_SS2   19      //Enable pin 2 (bass)
#define SPI_SS3   20      //Enable pin 3 (mid)
#define SPI_SS4   21      //Enable pin 4 (treble)

//Defines SPI groupings
#if !defined(CONFIG_IDF_TARGET_ESP32)
#define VSPI FSPI
#endif

//Sets clock rate for SPI protocol
static const int spiClk = 1;

//These global variables were used to interpret input through the mobile app
uint8_t port = 0x00;
uint8_t data = 0x00;

/*
array of SPI groupings, each index correlates to a different digital pot
spi_r[0] = Volume
spi_r[1] = BassEQ
spi_r[2] = MidEQ
spi_r[3] = TrebleEQ
*/
SPIClass* spi_r[4];

//Byte used for testing received SPI signal (MISO)
uint8_t received = 0x00;

/*
The potentiometers used in implementation were organized on a linear scale, requiring a logarithmic signal control for expected results. Instead of requiring
a direct computation for every update, a simple logarithmic conversion array was used
*/
int log_conv[31] = {0, 2, 4, 6, 8, 10, 12, 14, 16, 18, 
                    21, 24, 27, 31, 36, 42, 49, 56, 62, 70, 80, 
                    90, 101, 114, 128, 143, 161, 180, 203, 227, 255};

/*
The Following array was used for translation from an integer value to a boolean array for the SPI send. As the potentiometers
use a 16 bit command, the array was set to 16 bits. The first byte of this remains 0 regardless.
*/
bool ar_out[16] = {0,0,0,0,0,0,0,0,
                   0,0,0,0,0,0,0,0};


/*
The following function was used for integer to boolean array translation. The first 8 bits will always be 0, so after an initial reset, only indices 8-15 will be changed.
The array is reset to 0x0000 every update to avoid unwanted values potentially causing MCU burnout
*/
void ByteArray(uint8_t datain){
  for (int i = 0; i < 16; i++){
    ar_out[i] = false;
  }

  if (datain >= 128) {ar_out[8] = 1;}
  if (datain >= 64) {ar_out[9] = 1;}
  if (datain >= 32) {ar_out[10] = 1;}
  if (datain >= 16) {ar_out[11] = 1;}
  if (datain >= 8) {ar_out[12] = 1;}
  if (datain >= 4) {ar_out[13] = 1;}
  if (datain >= 2) {ar_out[14] = 1;}
  if (datain >= 1) {ar_out[15] = 1;}

}

//Function used for the actual SPI send
//*spi should be the specific index of spi_r correlating to the correct pot
//data should be processed and on a 256 scale (uint8_t)
void spi_bash(SPIClass *spi, bool dataout[]){
  digitalWrite(SPI_SCLK, LOW);
  digitalWrite(spi->pinSS(), LOW);

  for (int i = 0; i < 16; i++){
    delayMicroseconds(1);

    if (ar_out[i] == 0) {digitalWrite(SPI_MOSI, LOW);}
    else {digitalWrite(SPI_MOSI, HIGH);}
    delayMicroseconds(1);
    
    digitalWrite(SPI_SCLK, HIGH);
    delayMicroseconds(2);

    digitalWrite(SPI_SCLK, LOW);
  }

  delayMicroseconds(1);
  digitalWrite(spi->pinSS(), HIGH);
  delayMicroseconds(1);
  digitalWrite(SPI_MOSI, LOW);

}

//The following was declared globally to allow for callback functions regarding it.
BLEServer *pServer = nullptr;

/*
The following callback function is used for connection updates without reboots. Without restarting advertising, the system will not allow for other connections
once it has been connected to, even if the initial connected device was disconnected.
*/
class ServerAdvertControl : public BLEServerCallbacks {
  void onDisconnect(BLEServer* pServer) {
    delay(500);
    BLEDevice::startAdvertising();
  }
};

/*Callback class used for variable updating
Only used on the writable characteristic, the "onWrite" function specifically calls both the data processing and SPI send functions
This function is called any time *Datain is updated remotely
This function is works as an automatic updater any time a state is changed
*/
class DataInCallback : public BLECharacteristicCallbacks {
  void onWrite(BLECharacteristic *pCharacteristic) {
    String value = pCharacteristic->getValue();
    
    if (value.length() >= 2) {
      port = static_cast<uint8_t>(value[0]);
      data = static_cast<uint8_t>(value[1]);

      
      uint8_t processed_state = log_conv[data];
      //ByteTranslation(port, data);


      LastChangedPort->setValue(&port, 1);
      PortStates[port % 4]->setValue(&processed_state, 1);

      //spiCommand(spi_r[port % 4], pro= cessed_state);
      ByteArray(processed_state);
      if((port%4) == 2) {
        for (int i = 8; i < 16; i++){
          ar_out[i] = !ar_out[i];
        }
      }
      spi_bash(spi_r[port % 4], ar_out);
    }

    //SPI_Received->setValue(received);
    Serial.println(port);
    Serial.println(data);

  }
};


/*
The following is used for initial setup and one time functionality. All relevant code is in this function, due to the limitations of the software used for coding.
*/
void setup() {
  //SPI setup
  spi_r[0] = new SPIClass(VSPI); //Declares SPI class
  spi_r[0]->begin(SPI_SCLK, SPI_MISO, SPI_MOSI, SPI_SS1); //Assigns the SPI pins
  spi_r[1] = new SPIClass(VSPI);
  spi_r[1]->begin(SPI_SCLK, SPI_MISO, SPI_MOSI, SPI_SS2); //All assigned SPI pins overlap except for the SPI_SS*
  spi_r[2] = new SPIClass(VSPI);                          //SPI_SS* correspond to the unique enable pins of each bus
  spi_r[2]->begin(SPI_SCLK, SPI_MISO, SPI_MOSI, SPI_SS3); //This allows the databus and clock to be shared across devices
  spi_r[3] = new SPIClass(VSPI);                          //As the data is only written to a pot when its corresponding EN pin (SPI_SS*)
  spi_r[3]->begin(SPI_SCLK, SPI_MISO, SPI_MOSI, SPI_SS4); //Is set to LOW

  //Initializes pins used for SPI transfer
  pinMode(SPI_SCLK, OUTPUT);
  pinMode(SPI_MISO, INPUT);
  pinMode(SPI_MOSI, OUTPUT);

  digitalWrite(SPI_SCLK, LOW);
  digitalWrite(SPI_MOSI, LOW);
  
  //Iterable loop to simplify the addition or removal of signals
  //Also improves performance
  for (int i = 0; i < 4; i++) {
    pinMode(spi_r[i]->pinSS(), OUTPUT);
    digitalWrite(spi_r[i]->pinSS(), HIGH);
  }

  //Serial Setup
  Serial.begin(115200);

  //Bluetooth Low Energy Setup
  BLEDevice::init("TIAmpEsp");                                  //Server Initialization
  pServer = BLEDevice::createServer();
  pServer->setCallbacks(new ServerAdvertControl());

  BLEService *pService = pServer->createService(SERVICE_UUID);  //Creates a Service in the Server under which the Characteristics are organized

  BLECharacteristic *DataIn =
    pService->createCharacteristic(CHARACTERISTIC_RECEIVE0, BLECharacteristic::PROPERTY_READ | BLECharacteristic::PROPERTY_WRITE);

  DataIn->setCallbacks(new DataInCallback());                      //Initializes Callback, activating the "onWrite" function call
                                                                //This causes the program to update correlating SPI busses any time DataIn is changed
  DataIn->setValue(0x00);                                     //Initializes the value as 0x0000 for any initial reads

  LastChangedPort =                                             //This Characteristic Saves the last Changed Port, allowing for a short history
    pService->createCharacteristic(CHARACTERISTIC_UUID5, BLECharacteristic::PROPERTY_READ); //Mostly used for Proof of Concept and Debugging

  LastChangedPort->setValue(0x00);                              //Initializes the value for any initial reads

  //Pot State Characteristics
  PortStates[0] =                                               //Volume Pot State
    pService->createCharacteristic(CHARACTERISTIC_UUID1, BLECharacteristic::PROPERTY_READ);

  PortStates[1] =                                               //Bass EQ Pot State
    pService->createCharacteristic(CHARACTERISTIC_UUID2, BLECharacteristic::PROPERTY_READ);

  PortStates[2] =                                               //Mid EQ Pot State
    pService->createCharacteristic(CHARACTERISTIC_UUID3, BLECharacteristic::PROPERTY_READ);

  PortStates[3] =                                               //Treble EQ Pot State
    pService->createCharacteristic(CHARACTERISTIC_UUID4, BLECharacteristic::PROPERTY_READ);

  for (int i = 0; i < 4; i++) {                                 //Initialize all Pot States to 0 for initial read
    PortStates[i]->setValue(0x00);
  }

  //Characteristic for remote SPI Debugging
  /*
  For Proper behavior, connect the MISO and MOSI pins on the ESP. Doing so causes the ESP to read its own output as a Slave input
  This received data will be updated to SPI_Received, to verify integrity of all SPI sends
  */
  SPI_Received =   
    pService->createCharacteristic(CHARACTERISTIC_UUID6, BLECharacteristic::PROPERTY_READ);

  SPI_Received->setValue(0x00);

  //Activates the Service holding all declared Characteristics
  pService->start();

  //Advertises the Server for all incoming BLE connections
  BLEAdvertising *pAdvertising = BLEDevice::getAdvertising();
  pAdvertising->addServiceUUID(SERVICE_UUID);

  BLEDevice::startAdvertising();

}

void loop() {
  delay(2000); //All code runs through Setup. Permanent delay to keep from causing any errors or corruptions
}

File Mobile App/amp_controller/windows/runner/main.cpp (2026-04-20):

#include <flutter/dart_project.h>
#include <flutter/flutter_view_controller.h>
#include <windows.h>

#include "flutter_window.h"
#include "utils.h"

int APIENTRY wWinMain(_In_ HINSTANCE instance, _In_opt_ HINSTANCE prev,
                      _In_ wchar_t *command_line, _In_ int show_command) {
  // Attach to console when present (e.g., 'flutter run') or create a
  // new console when running with a debugger.
  if (!::AttachConsole(ATTACH_PARENT_PROCESS) && ::IsDebuggerPresent()) {
    CreateAndAttachConsole();
  }

  // Initialize COM, so that it is available for use in the library and/or
  // plugins.
  ::CoInitializeEx(nullptr, COINIT_APARTMENTTHREADED);

  flutter::DartProject project(L"data");

  std::vector<std::string> command_line_arguments =
      GetCommandLineArguments();

  project.set_dart_entrypoint_arguments(std::move(command_line_arguments));

  FlutterWindow window(project);
  Win32Window::Point origin(10, 10);
  Win32Window::Size size(1280, 720);
  if (!window.Create(L"amp_controller", origin, size)) {
    return EXIT_FAILURE;
  }
  window.SetQuitOnClose(true);

  ::MSG msg;
  while (::GetMessage(&msg, nullptr, 0, 0)) {
    ::TranslateMessage(&msg);
    ::DispatchMessage(&msg);
  }

  ::CoUninitialize();
  return EXIT_SUCCESS;
}

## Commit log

2026-04-20 initial commit
    Cole's Files
    [691137710002.step, 691210910002.step, 694108301002.step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]
2026-04-20 renamed folder
    included info about my subsystems
    [691137710002.step, 691210910002.step, 694108301002.step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]
2026-04-24 files
    all files
    [404 Capstone Execution Plan.xlsx, Capstone Validation Plan.xlsx]
